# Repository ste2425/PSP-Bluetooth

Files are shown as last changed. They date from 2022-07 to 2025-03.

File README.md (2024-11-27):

# PSP-Bluetooth

--- 

ℹ️ **Name Change**  This project was formerly called the `PSP-Consolizer`. The project has since been renamed to `PSP-Bluetooth` as the term `Consolizer` usually makes people think of video output which this project never worked with. 

If you wish to see the legacy `PSP-Consolizer` project it is accessible on the `legacy` branch [here](https://github.com/ste2425/PSP-Bluetooth/tree/legacy)

---

This project aims to add Bluetooth controller support to the PSP 1k, 2k and 3k models using an ESP32.

---

It aims to solve to problems:

- [x] Using the PSP as a consolizer
- [ ] Using the PSP as a dockable console (like the Nintendo Switch)

## Progress so far
* Fully functional hardware that replaces the UMD drive
* Partially functional hardware for portable version
* Fully functional consolizer implementation that works for both the 2K and 3K consoles
* Fully functional firmware that offer configurable controller mappings and OTA updates
* Single click programming via a Web app for Serial and OTA programming. No extra tools needed, it downloads the binaries and does everything
* Partially functional controller mappings via the web app.

## Web app

The web app can be found here [PSP-Bluetooth](https://ste2425.github.io/PSP-Bluetooth/).

## Repository Structure

### /software

This contains the firmware for the ESP32. It is built using the Arduino core and maanaged via the Arduino CLI. To build it the cli needs to be installed with the command `arduino-cli` globally available. 

See [it's readme](./software/Readme.md) for more info.

### /installer

This contains the software for the Web app. It as an Angular application built using Angular Material and deployed to GitHub pages via GitHub Actions.

See [it's readme](./installer/README.md) for more info.

### /Hardware

This contians all the hardware files for custom FPC's and the mod board itself.

See [it's readme](./hardware/Readme.md) for more info.

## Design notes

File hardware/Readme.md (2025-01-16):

# Hardware

This is the source for the Kicad project for the PSP Bluetooth hardware.

# Parts

I use JLCPCB for my assembly and as such the parts used are sourced from their catalog.

## Adding a part

See [Changing Parts](./ChangingParts.md) for more info.

## Generating JLCPCB production files

See [Generating Gerbers](./GenerateGerbers.md) for more info.

# Projects

# Analog

FPC for the analog stick intercept for 2K PSP's. This allows us to inject analog stick values without soldering to the console.

# Buttons Super

FPC for all the buttons intercepts for 2k PSP's combined into a single project. Fabs usually charge extra for all being combined into one.

# Center Buttons

FPC for the center buttons intercept for 2K PSP'script

# ESP

Project for the Mod Board which supports both portable and consolizer

# ESP-C

Project for the Mod Board which only support consolizers. The analog multiplexer for the analog sticks are missing here.

# Right

FPC for just the right buttons for 2K PSP's

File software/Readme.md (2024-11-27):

# ESP32 Software

This is the firmware that runs on the ESP32.

# Setup

 To build it the Arduino CLI needs to be installed with the command `arduino-cli` globally available. 

 Once setup in the scripts folder run `install.sh`. This will install all the needed board definitions and cores. It will also install the various libraries needed. Some libraries are to packaged via Arduino and are stored as zip files within this repo.

 # Building

 If you just wish to compile/build the firmware run the script `compile.sh`. This will not merge the bootloader binaries to flash the ESP32.

 # Building && merging

 If you wish to compile/build the firmware and also merge the bootloader binary (The CI does this) run the `build.sh` script.

 We need to do the merging for when uploading to the ESP32 via the web app. *If uploading without the web app use the `upload.sh` script*

 # Building & Uploading

 If you wish to compile and upload the firmware locally run the `upload.sh` script.

------------------------

 ℹ **Default Port** ℹ

 ---------------------

 The scripts are hard coded with the default port the ESP32 appears on for my development machine. If this is different for you, you will need to change it.

 # GitHub Actions

 See the `buildPSPBluetooth.yml` file in the `.github/workflows` folder in the root.

 ## Release binaries for the web app Issue

 See the readme [here](../releaseBinaries/Readme.md)

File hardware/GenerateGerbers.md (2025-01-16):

# Generate Gerbers

When generate production files for use with JLCPCB i use a plugin. This generates the Gerbers, zips them and generates the BOM and placement files.

## 1: Install the plugin

Follow the instructions here [https://github.com/Bouni/kicad-jlcpcb-tools](https://github.com/Bouni/kicad-jlcpcb-tools) to install the plugin.

## 2: Generate files

Click `Tools -> External Plugins -> JLCPCB Tools` menu item.

In the menu that opens you can do various things, most commonly remove items from the BOM and placement files.

**NOTE** it often likes to place test pads in the BOM file even though there is no associated part.

If the items listed as `TestPoint` have a green tick under either `BOM` or `POS` you will first need to highlight them in the list. Then click either `Toggle BOM` or `Toggle POS` to remove them from those generated files.

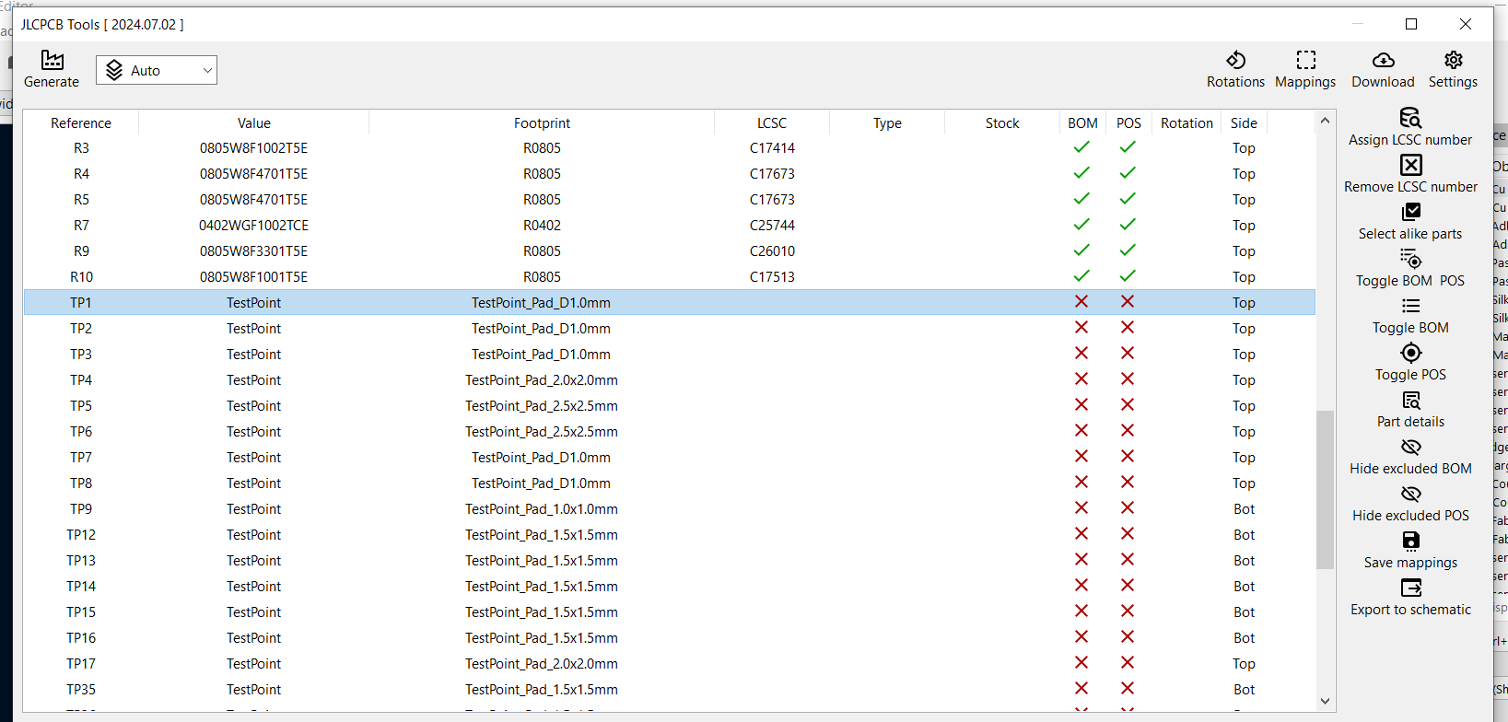
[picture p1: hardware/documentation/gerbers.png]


Once ready you can click `Generate` to generate the production files

## 3: Access files

The generated files will exist in `<clone-dir>PSP-Bluetooth\hardware\esp-c\jlcpcb\production_files` and can be uploaded to JLCPCB.

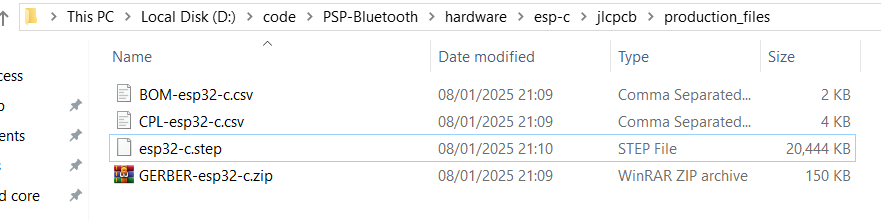
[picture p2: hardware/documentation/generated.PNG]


There may or may not be a `.step` file. This is just a 3D model of the PCB.

# Done

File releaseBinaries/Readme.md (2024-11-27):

# Release Binaries Folder

Due to CORS issues the web app can't download artifacts directly from a GitHub release. 

The CI instead commits back into the repository the compiled binaries in this folder. It then creates a new tag with the release number.

The web app then uses GitHub's RAW api and the release tag to find the binaries needed to flash to the ESP32.

**TLDR; ignore this folder and its contents, its for CI.**

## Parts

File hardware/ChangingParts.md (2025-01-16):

# Changing Parts

Sometimes it may be required to change parts, should some go out of stock.

This is my proccess.

## 1: Find the part

Using JLCPcb's part search is terrible IMHO. Instead i use a 3rd party here: [https://yaqwsx.github.io/jlcparts](https://yaqwsx.github.io/jlcparts).

The first time its used it will load up internally all the available parts to make them searchable. After that you have very fine grained search criteria to find exactly what you want.

### Considerations:
**Pick parts with footprints**. Whilst you can make your own, pick parts that have footprints.

Once you have found a part, click its part number.

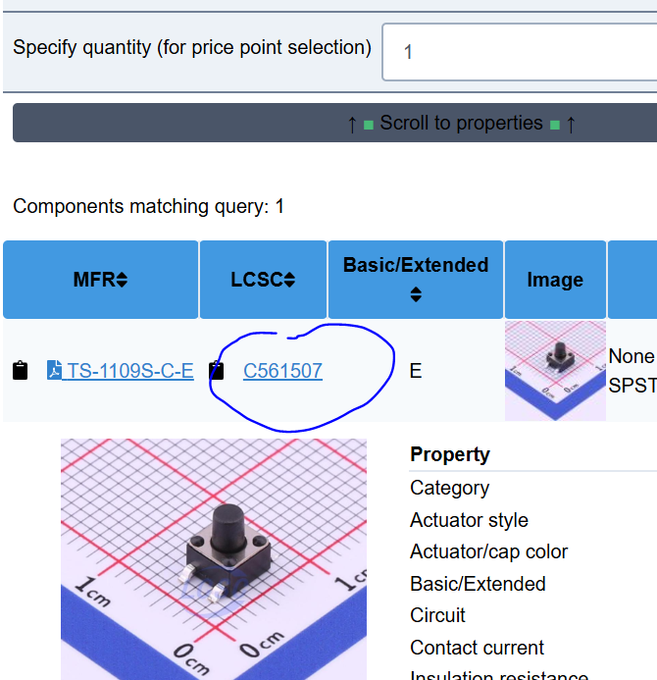
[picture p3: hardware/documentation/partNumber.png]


Then look the for `EasyEDA` button and click it.

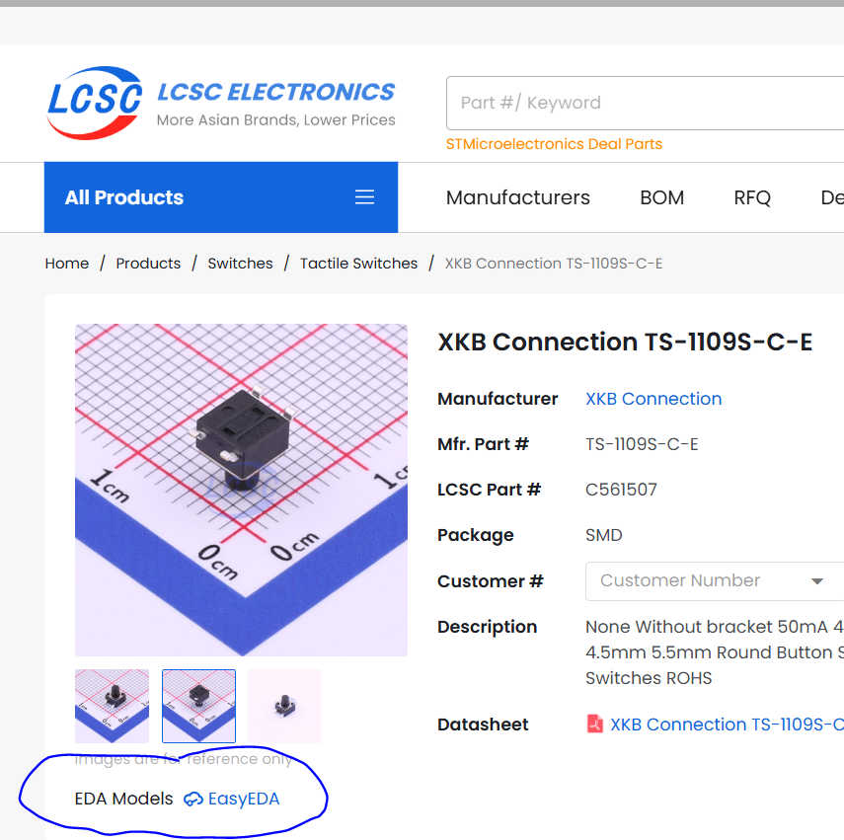
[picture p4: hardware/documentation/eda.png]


Then you can check its footprints.

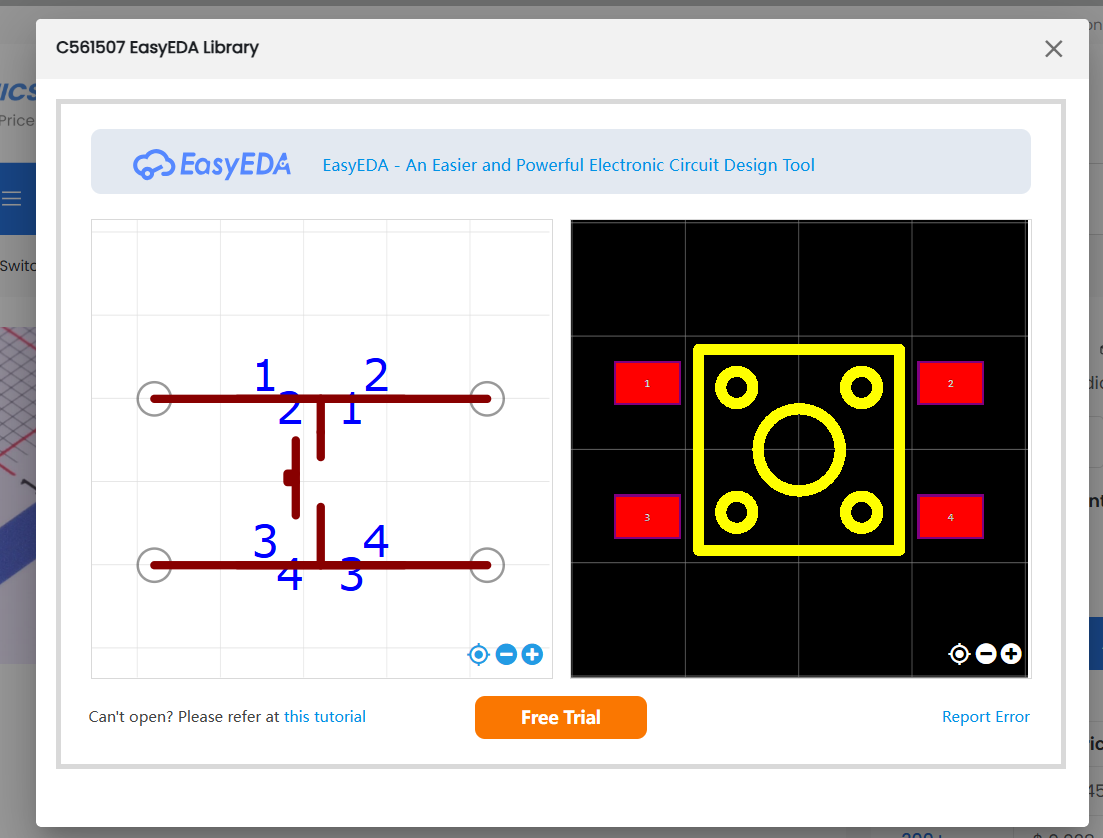
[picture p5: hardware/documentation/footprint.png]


Once you have found a part take note of its part number.

## 2: Add the part the the JLCPCB parts library

I run a script giving it the part number noted above. That script will download footprints for us and add them to a library linked to the projects in the repo. You can then use that part in any schematics.

**Don't have any projects open whilst running this script** Otherwise parts may not be available for use untill you close and re-open the Kicad project.

This script used a 3rd party python tool which can be installed from here: [https://github.com/TousstNicolas/JLC2KiCad_lib](https://github.com/TousstNicolas/JLC2KiCad_lib).

To sun simply right click the script `AddJLCPCBPart.ps1` and select `Run With Powershell`

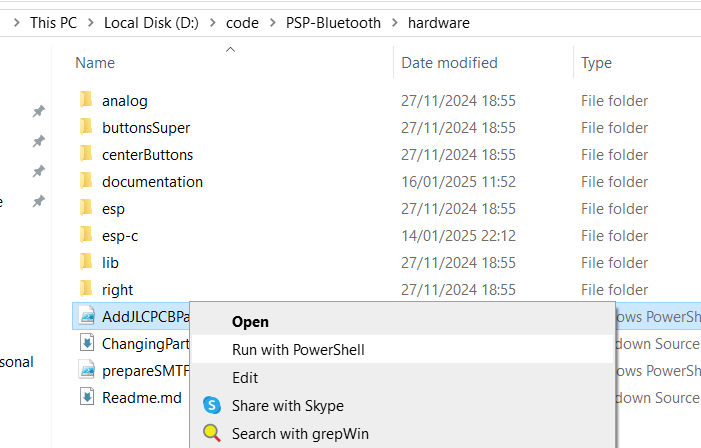
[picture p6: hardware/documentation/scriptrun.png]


In the terminal that opens paste the part number and press enter.

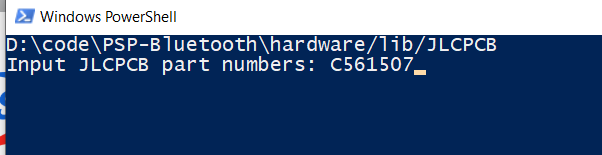
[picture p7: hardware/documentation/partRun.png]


Once done it will ask for another part number. You can either add more or close the terminal.

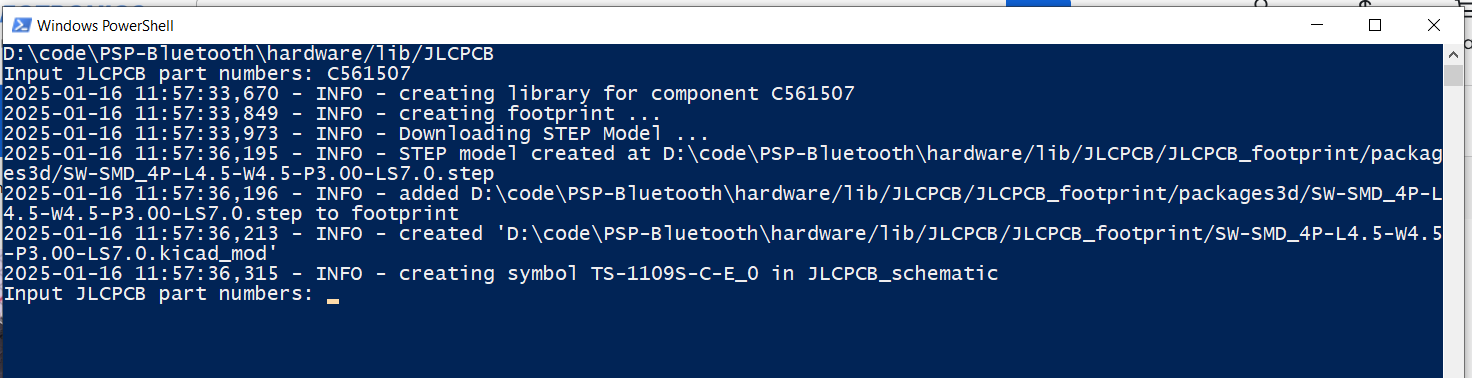
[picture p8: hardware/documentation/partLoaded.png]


The part is now available for use in KiCad

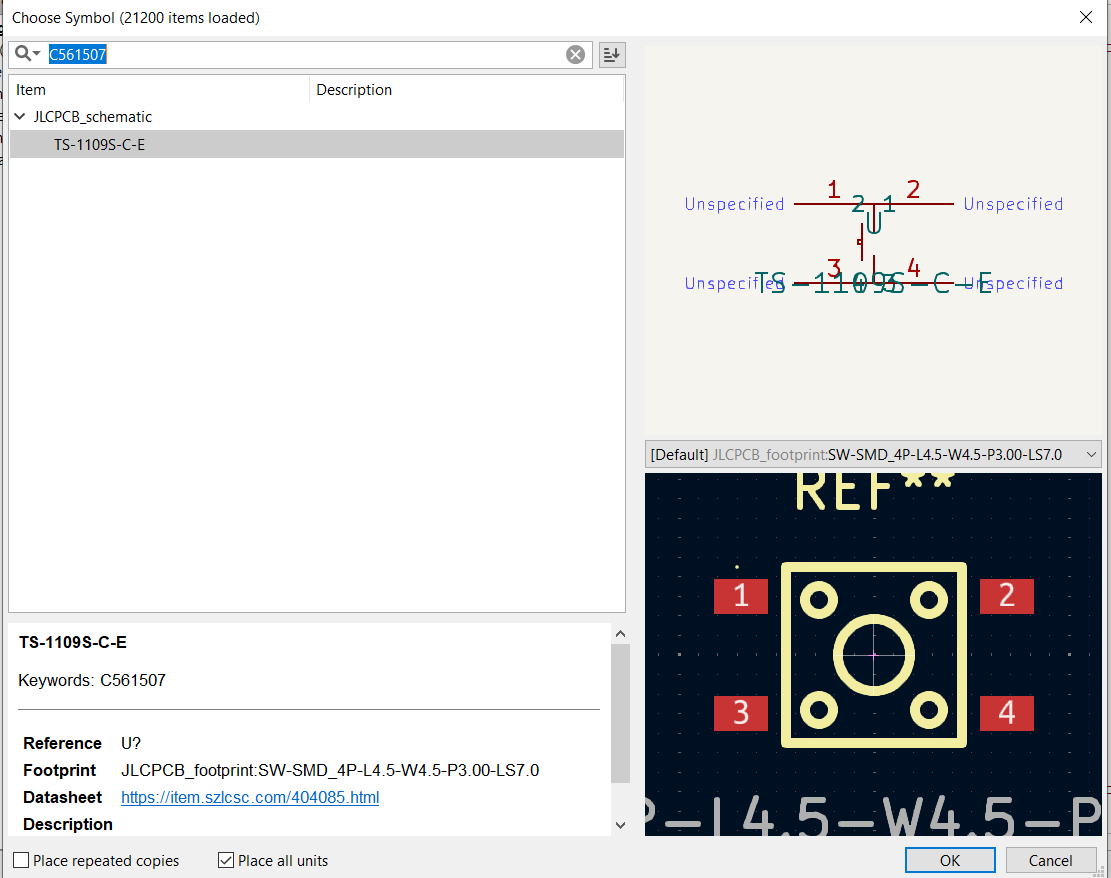
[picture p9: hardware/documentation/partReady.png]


## 3: Update Schematic

I would then remove the old part from the schematic and add in the new part, routing it correctly.

## 4: Update PCB

Then in the PCB Editor i would update the PCB from the schematic.

This will full in the footprints for the new components.

It will **not** remove the footprints for the old components.

I'd first delete the old footprints, then clean up the unused traces and via's using the `Tools -> Cleanup Track and Via's` menu item.

I would then place and route the new components footprints.

# Done

And that should be it, hopefully.

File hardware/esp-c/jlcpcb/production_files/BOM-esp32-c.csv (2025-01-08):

Comment | Designator | Footprint | LCSC
MCP23008-E/ML | U1,U4 | QFN-20_L4.0-W4.0-P0.50-BL-EP2.7 | C144211
CL21A106KAYNNNE | C13,C6,C9 | C0805 | C15850
0805W8F1002T5E | R2,R3 | R0805 | C17414
0805W8F1001T5E | R1,R10 | R0805 | C17513
0805W8F4701T5E | R4,R5 | R0805 | C17673
1N5819WS | D1,D10,D11,D12,D13,D2,D20,D21,D22,D23,D24,D25,D26,D27,D28,D29,D3,D4,D5,D6,D7,D8,D9 | SOD-323_L1.8-W1.3-LS2.5-RD | C191023
SS8050_C2150 | U3,U8 | SOT-23-3_L2.9-W1.3-P1.90-LS2.4-BR | C2150
TC1109DE26048 | U14,U15 | SW-TH_3P-L4.5-W4.5-P1.8-LS3.0 | C22459542
0402WGF1002TCE | R7 | R0402 | C25744
0805W8F3301T5E | R9 | R0805 | C26010
CL21B105KBFNNNE | C5 | C0805 | C28323
TS-1187A-B-A-B | BOOT1 | SW-SMD_4P-L5.1-W5.1-P3.70-LS6.5-TL-2 | C318884
MICROXNJ | USB1 | MICRO-USB-SMD_MICROXNJ | C404969
CL21A226MAQNNNE | C1,C11 | C0805 | C45783
AFC42-S14FMA-1H | U13 | CONN-SMD_14P-P0.50_L3.1-W9.0 | C466533
CC0805KRX7R9BB104 | C10,C12,C2,C4,C8 | C0805 | C49678
IPFP051A30472R5 | U7 | FPC-SMD_4P-P0.50_C9900013912 | C5127055
HC-FPC-05-09-10RLTAG | U10,U11,U6 | FPC-SMD_10P-P0.50_HC-FPC-05-09-10RLTAG | C5213750
MCP42010T-I/SL | U5 | SOIC-14_L10.0-W5.5-P1.27-LS7.8-BL | C54781
AMS1117-3_3 | U9 | SOT-223-3_L6.5-W3.4-P2.30-LS7.0-BR | C6186
ESP32-WROOM-32E(4MB) | U12 | WIFI-SMD_ESP32-WROOM-32E | C701341
CH340C_C7464026 | U2 | SOP-16_L10.0-W3.9-P1.27-LS6.0-BL | C7464026
FC-2012HRK-620D | LED1 | LED0805-R-RD | C84256

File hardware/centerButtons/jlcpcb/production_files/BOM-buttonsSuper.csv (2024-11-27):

Comment | Designator | Footprint | LCSC
5034801000 | P1 | FPC-SMD_5034801000 | C127355

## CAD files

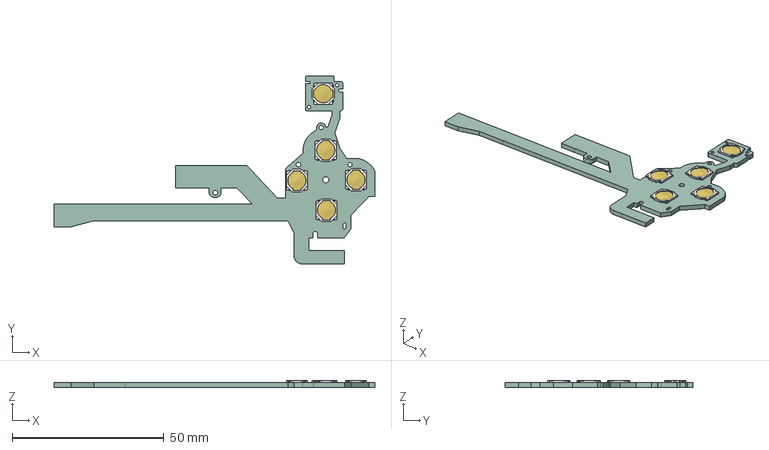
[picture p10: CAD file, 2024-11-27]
hardware/right/right-fpc.step
105.9 x 62.0 x 2.35 mm
KEY-SMD_4P-L7.5-W7.0-H0.6-P5.0 x 5
right_PCB

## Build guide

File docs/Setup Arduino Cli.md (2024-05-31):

# Setup Arduino Cli

* sudo apt-get update
sudo apt-get install python3-pip
pip3 install pyserial

arduino-cli compile --fqbn esp32-bluepad32:esp32:esp32 .
Traceback (most recent call last):
  File "/home/stephen/.arduino15/packages/esp32/tools/esptool_py/4.5.1/esptool.py", line 31, in <module>
    import esptool
  File "/home/stephen/.arduino15/packages/esp32/tools/esptool_py/4.5.1/esptool/__init__.py", line 41, in <module>
    from esptool.cmds import (
  File "/home/stephen/.arduino15/packages/esp32/tools/esptool_py/4.5.1/esptool/cmds.py", line 14, in <module>
    from .bin_image import ELFFile, ImageSegment, LoadFirmwareImage
  File "/home/stephen/.arduino15/packages/esp32/tools/esptool_py/4.5.1/esptool/bin_image.py", line 14, in <module>
    from .loader import ESPLoader
  File "/home/stephen/.arduino15/packages/esp32/tools/esptool_py/4.5.1/esptool/loader.py", line 30, in <module>
    import serial
ModuleNotFoundError: No module named 'serial'

Used platform         Version Path
esp32-bluepad32:esp32 4.0.4   /home/stephen/.arduino15/packages/esp32-bluepad32/hardware/esp32/4.0.4
Error during build: exit status 1

arduino-cli compile --fqbn esp32-bluepad32:esp32:esp32 .

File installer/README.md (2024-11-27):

# Installer

This is the source code the the Angular Web app.

It is built in TypeScript and uses Angular Material for its UI components.

It also uses Web Serial and Web Bluetooth API's for programming the ESP.

Serial programming is provided by the [ESPtool-js](https://github.com/espressif/esptool-js) library provided by ESpressif.

As such it only works on Chromium bases browsers.

# Release binaries for the web app Issue

See the readme [here](../releaseBinaries/Readme.md)

# Installation

Ensure NodeJS is installed and the command `npm` is globally available.

Within the `installer` folder run `npm install`.

# Starting

Within the `installer` folder run `npm start`. The terminal output will report the URL for the web app locally.

# Hosting in GitHub

See the `buildPSPBluetoothWebProgrammer.yml` file in the `.github/workflows` folder in the root.

## Routing problem

The app is hosted within GitHub and deployed using GitHub actions. There was some jiggery-pokery to make the routing work.

GitHub expects a static site where every page is its own `html` file. Angular is an SPA where there is a single root `index.html` file and routing is handled via JS.

These two worlds clash. If you hit the root of the site, navigate to another page say `/serial` then hit F5 you will get a `404` page from GitHub. This is because GitHub is looking for a html file called `serial.html` which obviously does not exist.

### Routing Solution

The solution is to duplicate, via CI, the compiled `index.html` and rename it for every route the application has.

## Route Case Sensitivity Problem

GitHub pages routes are case sensitive. IF the route is `/serial` but you hit `/Serial` it will get a `404`.

What we do is have a `404.html` page in the root which GitHub actions hits. Some JS checks the current URL, lower cases it and compares it to a list of expected routes. If it matches it will redirect the user to that correct casing of that route.

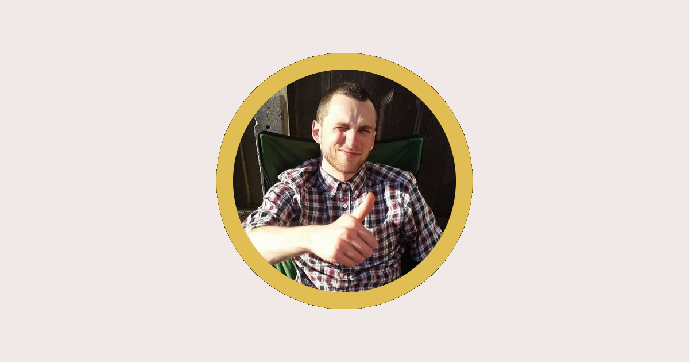
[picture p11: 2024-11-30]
installer/src/assets/thumb.png

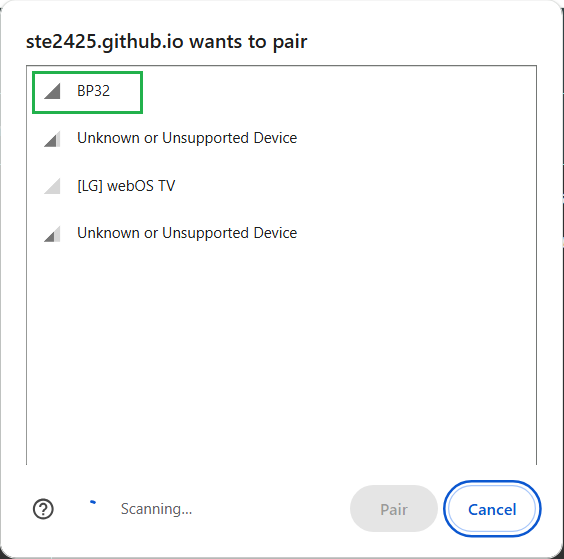
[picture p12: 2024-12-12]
installer/src/assets/pairDialog.png

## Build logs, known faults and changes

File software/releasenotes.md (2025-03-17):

# Release 2.3.2 - PRE RELEASE

## Features
 N/A
## Changes

## Saving mappings doesnt reset active mapping
When saving mappings via the web editor the currently active mapping will remain the active mapping.

However this is based on mapping number. Imagine you have three configured mappings, with the last one active.
If a mapping is deleted so there is now only 2 active mappings. In this situation the currently active mapping will still be reset back to mapping one.

## Bug fixes

## Saved button mappings not applying correctly

When saving button mappings via the Web UI they were not saving correctly when a controller is connected.

Now they should update correctly. Note: *The active mappings resets to the first mapping*.

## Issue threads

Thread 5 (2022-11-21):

Build buttons mappings tool via USB

ste2425, 2022-11-21:
Build a utility that will allow the user to create custom button mappings.

Once inplace this will allow for future enhancements such as per game mappings.

The ideal solution will be a Web APP communicating with the Arduino via Web Bluetooth however until https://github.com/ricardoquesada/bluepad32/issues/30 is implemented thats not possible.

Instead build an electron app that comms with the Arduino via serial.

It should be built in scuch a way that the Core is re-useable within a web app and the serial comms are abstracted such that they could be relaced with BT comms when aforementioned feature request is complete.

In theory much of the ground work will be done here so that when its possible to use Bluetooth comms instead of Serial it wont be a big task.

Closed 2023-06-02.

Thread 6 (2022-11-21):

Implement quick shutdown

ste2425, 2022-11-21:
Currently the Consolizer will shutdown when a controller turns it self off, disconnecting.

The time this takes varies per controller the PS4 takes around 7-8 seconds holding the PS button. XBOX one S controller take around 3 seconds holding the XBOX button.

Instead we should instruct the controller to turn it self off. That way the shutdown time can configurable by the user, defaulting to a much shorter time. It can also be consistent across all controllers.

Initial WIP implemented on branch `feature/quickShutdown` but relies on the following https://github.com/ricardoquesada/bluepad32/issues/26 to go live in version `3.5.2`

Closed 2024-07-22.

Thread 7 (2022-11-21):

Build internal hardware version

ste2425, 2022-11-21:
There is enough space in the PSP to fit an Arduino inside if the UMD drive was removed.

Building a PCB to fit all needed hardware _should_ work and be reasonably easy.

The difficulty is finding a way to connect the original PSP's face buttons and the Arduino to the PSP's connectors at the same time.

I have tried numerous ideas and the best option seems to be to replace the original button FPC's with custom ones that provide easy access solder pads to connect the Arduino too.

However looking to have these made in a low volume prototype stage seems terrible expensive and beyond my means as a hobby project.

If anyone with greater hardware skills than mine (i don't have much) could figure this out that would be great, i would happily make any needed software changes.

Here are a couple of blog posts on the subject if people would like to see more information on my investigations.

https://ste2425.github.io/21/12/2022/PSP-Internal-Consolizer-Making-Connections/
https://ste2425.github.io/08/01/2023/PSP-Internal-Consolizer-Fitting-FPCs/

**As of right now (3/4/223) this feature is on hold**. Currently this is a consolizer project and will remain that way. In the future when either my skills improve, or my disposable income increases i will re-investigate this feature.

ste2425, 2024-07-22:
So this is in active developent and going well targeting an ESP.

A PCB is current 1/3 of the way through being designed. Once done targeting other PSP's, such as the 3000 or 1000 should be allot easier as all that is needed is custom FPC's specifically for those consoles.

However arguably the 1000 is only useful with the HDMI mod installed too, however that also occupy the UMD space so can't be used at the same time.

ste2425, 2024-11-07:
In yet so version is pretty much done and being built as the standard for the ESP32 platform.
closing this as internal is just the norm now and not an additional feature like it was the for Arduibo.

Closed 2024-11-07.

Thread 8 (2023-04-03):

Implement PSP 3000 support

Bma36, 2023-04-03:
I want to make it for my psp 3000, is it compatible? do you have twitter to follow your work?

ste2425, 2023-04-03:
It currently doesn't support the 3000 yet.

The pinout of the various internal connectors on the 3000 is different to the 2000. Sadly i don't have a 3000 to figure out the pinout of these connectors and modify the hardware to make it compatible.

It would be an easy task to make it compatible but i won't be in a position to purchase a 3000 for a while to investigate.

If you, or anyone else interested in this project, has a 3000 and the ability to open it and figure out that pinout i would happily make the changes needed to support it.

Bma36, 2023-04-03:
Yes, I have a psp 3000 and I can help you by dismantling and taking photos of the connectors, your twitter is restricted, you can't follow it, if you want the connectors' records just say so.

https://twitter.com/Am60691019?t=VmD2-d7xX93HxiJeVbyZvA&s=09

this is my twitter if you can follow it so i can follow back i'll be grateful

Bma36, 2023-04-05:
https://github.com/DobaMuffin/PS2PSP

this is another project to use the ps2 controllers made based on the psp 2000 and was adapted for the 3000, maybe it can help you

Bma36, 2023-04-08:
Up

hpx1984, 2024-05-09:
hi Sir ste2425

how about PSP1000, is it can support too?

Doyle4, 2024-07-19:
From looking at Issues I can see this project is no longer worked on or the dev is not interested in peoples requests, did anyone find a alternative that works on all?

ste2425, 2024-07-19:
Pleas try to avoid passive aggression in order to get a developers attention and/or try an pressure them into working on something for you.

I am actively working in this and I’d you check my YT you would see somewhat regular uodates on this project.

I am doing this in my own time for fun. As such I will be working on it in a timescale that’s fits around my personal and family life.

If you or anyone else for that matter wishes to contribute to help move this project forward I’d happily collaborate with others.

Right now the ESP is working. You can controll all the PSP’s buttons and I’m 1/3rd the way through designing the PCB to fit in the UMD space.

I will try and more regularly push to this repo and post YT videos on the project though.

Doyle4, 2024-07-22:
Passive aggressive?
May 9th 2024 most recent issue, then its a whole year a question was asked unanswered, May 2023, not passive aggressive, clear statement to what looked liked an abandoned project.

Did you run out of bubblewrap to protect yourself from words? Damn…

ste2425, 2024-07-22:
@Doyle4 there is no need to end your comment with sarcasm or just generally being unpleasant.

Let’s try and keep this civil shall we, this isn’t Twitter. If you are wanting me to continue building something for you to use at no cost to your self that is probably the best way to go about it.

Like I say if you wish to contribute to this project to move it along faster I will gladly accept PR’s.

I you wish to help push forward 3000 support open your PSP3000 and send me high res scans of the button FPC’s both sides and back. This is what I lack as I do not own a 3000 yet.

ste2425, 2024-11-07:
Just an update.

3k should be supported now. For consolizers the latest hardware variant should support it out the box.

Portables will need custom FPC’s which when I’m finished to firmware I will build. They are just variants on the 2k however so should be very quick to do.

ste2425, 2025-02-19:
Closing this. All variants of the psp 2 and 3k are fully supported .

Closed 2025-02-19.

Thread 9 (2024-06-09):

Updates for you I filmed a video tutorial!!

Shtonksareup, 2024-06-09:
Hey there @ste2425,

So I may have gone overboard... haha I just got my set up semi video ready and I really wanted to film a tutorial because 1. I saw people commenting on your short saying it was fake since their is no tutorial, which is dumb but what ever. 2. I was looking for this exact project for what felt like ages, and every reddit post claims its impossible.... well clearly not. I want to make sure you get all the credit for your work though. I just put the thing together and filmed it. I will add a google drive link to the video so you can watch it. Ignore the audio for now, I plan to put graphics on it and dub over my voice for directions. Since I do a full psp teardown and the install. I want people to be able to skip around the tutorial as easy as possible. The only thing I will say in the video that is feedback on the current BOM is that the Right 14pin connector cable I think should be opposite sided, not the A type. both builds I did I had to get funky with the cable to get it to fit in right, but the opposite side one would let you do two angled bends and fit the right way :). I will explain that in the video the rest will literally just be a video form of your build guide with a little extra direction and help for people who are visual.

I have a small YT channel with my brother where we play games, but I would not be upset if you felt like the video should be posted on your channel since you did all the work :D you take a look at the video and let me know what you think.

PS ( I had to watch a YT video on how to submit an issue, for the first time ever I know how my parents feel when I help them with their email or other various tech issues haha)

Here is the link for the video with no audio dubbing yet
[Video Link](https://drive.google.com/file/d/1I4zoUzjQbjUgBxGIB0SeaWKbQubcTaRH/view?usp=sharing)

I am also working on a potential shell the can be printed and will cover the system, that will take more time since I have to wait for my prints to finish and then test and correct. But I have a cool design i am starting to like :D

Edit: Here is the default base
[PSP defult BT PCB mount.zip](https://github.com/user-attachments/files/15807657/PSP.defult.BT.PCB.mount.zip)

I also finished and tested my custom shell. Here are the files for that as well
[PSP Custom Shell Base and Top.zip](https://github.com/user-attachments/files/15807700/PSP.Custom.Shell.Base.and.Top.zip)

Shtonksareup, 2024-06-10:
@ste2425 Not a problem at all! I am coming off a super busy period myself and starting Wednesday I have am taking a bunch of time off since I am a teacher. I figure you will respond when you can so no rush on that kind of stuff.

I have always loved taking things apart so I wanted to make videos about that, but just don't really have the time haha! This just felt like the perfect thing to film especially with there not being one out there yet.

Don't change what your doing at all! I think splitting them into two projects makes the most sense, but I honestly wouldn't do anything else with the BT project in terms of soft ware. It is fun you say your a software guy and hardware isnt your thing I tell my friends the exact opposite. It was so nice for me that all I had to do is plug the Arduino in and hit run. That is honestly what most people would want. Thats why I don't think you need to change anything or offer additional features to the "external BT build" All I wanted as PS controller button support so I could play a few of the PSP games I love on the big screen. With out getting to technical and off track. I think a lot of people aright now are getting home set ups with upscalers, that's the reason I even wanted to do the build in the first place.

Back on track, I think if you split it into two things and we add the video link/ stl files for the new external shell ( its super basic but adds a little protection. Then leave that project alone. I have played for around 10 hours or so on and off over the past few weeks and I have only ever had it desync once on me and all i did was press the button on the PCB and i was playing again. So I am sure there are people who would want more from you and there are more features that people would want but put all that work into the new project. The old one can be for people like me who have a psp with a busted screen, of in my case I had a MOB that no matter how many different 2000 umd drives I tried it still wouldn't read disks. So something on the board was messed up and I held onto if for parts, but it was the perfect board for this build. Plus if the video helps some people build it and it catches any steam I am sure someone else would pop in and mess around with the Arduino if they really wanted to.

I watched your video about the current updates, and I think there is a whole group of people that would like the new build you are working on and the fact that it would work for all models would be great. (There are lots of comments asking for that im guessing cause people want to use what ever psp they already have) This project though wasnt to expensive. I bought enough parts for 2 builds and with the tv cable and the second PSP i bought it cost me like $200 USD I have a break down in the graphics I am adding to the video. I think for a bit over $100 a lot of people will want to do this build. The modding community is huge, and some mods are way to expensive. I did one on my original Nintendo a few weeks ago and the parts alone cost me $120. Im getting off topic again though sorry.

Summing up. You should work on what makes you excited. Its a fun project so don't change what your cause I have time put into the old project. I think they both have uses, and I think people will enjoy building them both or just one or the other for their needs. If they want plug and play and have a broken PSP like me then they are in luck. If they want way more freedom, and control buttoned down into the old shell then you have that in the works and they could help/ keep tabs on the project! you keep doing what you are doing. I think the split into a finished or released version of the external build and then a in the works internal build would be perfect.

I will stop going on and on now haha. I am away for the next day and a half, but I am hoping to finish the video by Friday, I had to do some final reprints last night and I want to film the extra shell assembly.

Shtonksareup, 2024-06-10:
@ste2425 I got the chance to get the shell printed, so use this video link, I will check my email to make sure I approve your request this time. [Video with the shell at the end](https://drive.google.com/file/d/1I4zoUzjQbjUgBxGIB0SeaWKbQubcTaRH/view?usp=sharing)

Shtonksareup, 2024-06-13:
Alright @ste2425 Here is the link to the finished video, I sent an email over to you, but Im not sure if they made it so I am adding it here for you to take a look at. Make sure I got your name right! :D
[Video with all finished audio](https://drive.google.com/file/d/1l1CTqXvrykbftFFA1gyGjSH0_6XYXhdx/view?usp=sharing)

ste2425, 2024-06-13:
hey @Shtonksareup sorry I've been meaning to respond the past couple of days.

The video is fantastic. Super good quality and in-depth.

I think i will publish a new release with your version of the mount stl as it looks allot better than what ive built.

Really interesting point about the firmware upgrade and TVout, i never considered that and certainly something to be aware of.

Are you on twitter/discord/YT? Would you be open for a DM to chat about this project? I'll be easier to get hold on on one of those platforms.

Shtonksareup, 2024-06-13:
@ste2425 Thank you so much for saying all of that I really appreciate it!! Yeah I am on discord and youtube I probably check discord more though if you give me your discord name I will add you mine is zeldandlink that should work. :D DM would be way easier.

ste2425, 2024-06-14:
@Shtonksareup Neat, ive ive done it right i should have sent a request over to you. Or if not some random internet person!

Shtonksareup, 2024-06-14:
@ste2425 I think I added you. I sent a little message :) if you didnt get one then I added some one else 👀

Closed 2024-07-16.

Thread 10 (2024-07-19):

really 140 Ohm Resistor?

Liriel-666, 2024-07-19:
really 140 Ohm Resistor for the LED? Thats a Really unusale Resistor and hard to find.
Most sell only 130 or 150 Ohm als normal.
140 ohm as smd yeah easy to find

ste2425, 2024-07-22:
Hey, to be honest when i designed the PCB i didn't know any better! I think i arrived at value either from a guide i followed or some resistor calculator.

If there is a better value you can recommend i will gladly update it to help others.

ste2425, 2024-11-07:
Closing this. The schematic being reference is for e older Arduino version. The newer ESP version doesn’t have such issues, I don’t think.

Feel free to re-open and Ofer a PR to fix if this issue still exists.

Closed 2024-11-07.

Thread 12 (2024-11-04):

Pressing X Puts the PSP to Sleep?

Grae87, 2024-11-04:
Hi, sorry if this is something basic, but everything seems to work except the X button. When I press it, the console goes to sleep.

I've checked continuity with all the points. I can't find any bridging or cold solder points.
No issues came up with the Arduino flash either.

Can anyone help?

ste2425, 2024-11-04:
The FFC which controls the PSP’s power button is on the same connector as the X button (and all the others on that side for that matter)

My first port of call would be to verify the FFC is correctly seated at both ends. Also ensure is is not obviously damaged.

When building this many times I had nudged one of the cables causing behaviour like this.

Once one of them had an internal break causing similar behaviour but that seems rarer from my experience

ste2425, 2024-11-26:
Closing this as stale. Please re-open if any new information is available.

Closed 2024-11-26.

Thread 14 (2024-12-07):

Future feature of V2 BT Mod Board (visually logging the paired controller button presses)

Shtonksareup, 2024-12-07:
Of all my ideas I think this has the most quality of life potential for future users. A display on the mappings page that shows the user the current mapping for a button they are pressing on their controller. This would allow users to identify the current settings in real time allowing for greater ease of use over the large variety of compatible controllers.

Most AAA/ huge tech companies follow the same basic layout for controllers but for something like an xbox adaptive controller, or a retro BLE controller where the layout is significantly different this would allow users to see what the buttons are mapped as and change them as they see fit.

Great work as always Stephen and no rush or timeline on this idea just logging so I don't forget about it.

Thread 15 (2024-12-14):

How to program from localhost?

Darthagnon, 2024-12-14:
The current implementation looks like it depends on https://ste2425.github.io/ to program the controller - is it possible to program instead from a website running off my laptop, or via USB? I would prefer not to depend on a website that will be 404 in a few years to program hardware.

ste2425, 2024-12-14:
Thanks for the interest in my project!

First of all https://ste2425.github.io/ is me, it is my GitHub username and all the various URLS off that are my repositories with GitHub pages configured, ‘PSP-Bluetooth’ being this repository.

This repository contains *everything* needed for the PSP-Bluetooth project to function, the hardware files, firmware source and the web app source. The readme documents this and explains the repository structure.

So long as this repository exists the web app will exist, so essentially so long as the project exists the web app will!

hopefully that alleviates any concerns you have @Darthagnon.

However everyone are free, and encouraged, to fork this repository. Make changes and enhancements.

So if you wish you can fork the repo and follow the instructions in the read me to run the web app locally.

ste2425, 2024-12-16:
As there’s been no response going to consider this problem solved. Please reopen if still having concerns.

Darthagnon, 2024-12-24:
Thank you for the info! I will try running the website from the repo off localhost.

I was a bit worried as similar projects that used direct-from-web updates for writing firmware (e.g. [Google Stadia](https://garyodernichts.blogspot.com/2023/01/looking-into-stadia-controller.html), [Henlo for PS Vita](https://github.com/SKGleba/henlo_jb)) did not work offline and needed extra work to be suitable for long-term usage.

ste2425, 2024-12-24:
It’s also worth adding for programming the web app is purely a convenience.

You can download the binaries from the release and program the ESP32 using your referred programming method.

Closed 2024-12-16.

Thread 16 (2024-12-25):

Setting cycle through mappings to stick click and Select + Start + left or right on dpad

Shtonksareup, 2024-12-25:
Just logging this so we don't forget. that button combo will be weird to do with one hand but I think every controller will have those buttons where some will not have thumb stick buttons.

ste2425, 2025-02-07:
Closing as fixed in version 2.2.0.

There will be enhancements to this in #19

Closed 2025-02-07.

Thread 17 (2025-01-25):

コントローラーの右スティックの斜め入力

niasuniasu, 2025-01-25:
コントローラーの右スティックをD-Padに設定した時、斜め入力が出来ないのですが、出来るようになりますか？

ste2425, 2025-02-02:
This is something i was hoping i would get away with not being an issue.

Lets say the range of the analog stick is -250 - 250. To trigger a button press it has to be over 20 from the end of its range (so -230 or 230).

Trouble is because the analog stick gate is a circle if the stick is in the top left diagonal the left value may be something like -200 and the top value 200. So they are outside the threshold to trigger a value.

I could lower the threshold but that would make the analog stick feel too sensitive for some.

I need to have a think, i have an idea on how to detect if its a diagonal.

Jonnicom, 2025-02-03:
I am glad to see both this and the other issue that you combined with an earlier submitted one are at least on the radar.  I agree, the right stick works ok as it is, but it would be nice to see some type of diagonal integration eventually.  Thanks for all you do, this is a great project!

ste2425, 2025-02-04:
The pre-release build 2.2.0-rc2 has a fix for this implemented.

I have lowered the thresholds slightly and diagonals work in my testing.

It feels ok to me but that is very subjective.

Feel free to give it a try (can be installed from the web app using BLE).

I will consider this resolved if i don't hear otherwise :)

thanks.

Jonnicom, 2025-02-05:
> It feels ok to me but that is very subjective.

Subjective indeed!  It's going to be different for everyone, and perhaps even game-to-game, just depending on how the player is trying to implement it.

I have my right stick on a Dualsense mapped to the PSP Dpad, and after testing it in Metal Gear Solid: Portable Ops, it works, but it is very picky.  Have to be pointing precisely at the 45 degree angles, or you'll still just get up or right/up or left, etc.

But, in practice it is working and seems possible.  I guess adjustments can be tested from here on out.  I wonder if there is any way to implent the user being able to adjust this sensitivity on their own in the future.  But, I am also aware that we're essentially mapping 4 buttons in an attempt to "fake" 4 additional directions.

I'll keep testing it any other games I can think of in the next few days and give more feedback to try to help out!

ste2425, 2025-02-05:
Thanks for testing this out so quick!

Yea I was on the fence if this would be acceptable or not. Decided to wait for use feedback.

It would be good to have it user controllable.

Need to try and set sensitivity for the four directions and the four diagonals seperatIy i think.

Lowering the threshold any more to account for diagonals I think will reign the feel of  the four main directions if that makes sense.

I think rather than over engineering at this stage I will make it configurable. If it turns out that isn’t enough to make both the  diagonals and the four main directions comfortable then we will have to rethink.

Sent from Outlook for iOS<https://aka.ms/o0ukef>
________________________________
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

ste2425, 2025-02-07:
Closing as fixed in version 2.2.0.

There will be enhancements to this in https://github.com/ste2425/PSP-Bluetooth/issues/19

Specifically to make the diagonals work better.

Closed 2025-02-07.

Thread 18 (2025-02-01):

L1 + R1 + Right D-Pad doesn't allow Right D-Pad to work

Jonnicom, 2025-02-01:
I am using a DualSense PS5 controller on a PSPlaceable and have not had the change to test any other controller at this time.  But, when using L1 as L on the PSP, R1 as R on the PSP, and Dpad as Dpad, pressing right on the DPad will not work if you also have L1 and R1 held down.  Can be repeated and demonstrated in games such as Metal Gear Solid Portable Ops 1 and 2.  What's odd is, mapping the L and R functions on the PSP to L2 and R2 on the controller works fine...

ste2425, 2025-02-02:
This is linked to #16 i think.

The button combo `L1` & `R1` & `DPAD Right` is a reserved combo that cycles through to the next configured button mapping.

The reason `L2` / `R2` works is because that is not checked for this reserved mapping.

I thought it would be unuque enough, i didn' realise there were games which used it.

Closing this as i think #16 will solve this problem. Please comment on that issue if that combo wont work.

Closed 2025-02-02.

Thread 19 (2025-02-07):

Add extra config options

ste2425, 2025-02-07:
Add a UI to configure the following things

* Power LED brightness
* Threshold to trigger button press when controllers with analog triggers are  mapped to buttons.
* Threshold to trigger button press when analog stick is mapped to buttons.
  * This includes dealing with diagonals better.
* Ability to make button combo les difficult
  * Option to juse use `select` & `start` or use `select` & `start` & `R1` & `L1`

Jonnicom, 2025-02-08:
Very much looking forward to the work on the right stick and thresholds, etc!  The current build did enable it, but I don't think it's sensitive enough.  It is extremely specific in Metal Gear Solid Portable Pps, and doesn't work at all how you'd want it to when mapped to the face buttons for a first person shooter like Ghost in the Shell.  But, that's just what I've found in my testing so far.  Glad it's on the radar!

ste2425, 2025-02-14:
@Jonnicom FYI there is a prelease version 2.3.0-rc4.

Along with a new settings page in the web app.

If you have the time maybe you could give it a try. It allows a number of different settings to be toggled, analog stick threshold being one of them.

It is very experimental so you may encounter issues though!

Jonnicom, 2025-02-15:
@ste2425 Tested/Testing now, but yes, wow, what a difference lowering the threshold makes!  Feels closer to real analog input than ever before.

It's still obvious that it's a "gated" 8 direction input, but, I think that's the best you can get considering it was never true analog directional control to begin with.  Still much prefered to use this than using the 4 face buttons to move a camera, especially in first person shooters.  In fact, when in quick movement and motion, you almost can't *tell* that it's gated 8 directions, it does feel rather fluid with the threshold all the way down.  Great job!  I also tested the trigger sensitivity using a dualsense, I can't really feel much of a difference either way myself, but I'm not sure if the dualsense even uses analog triggers or if I'd notice either way!

Out of curiosity, is the analog threshold setting for adjusting just the right stick, or both left and right at the same time?

I don't see any change in the LED brightness, however - not a huge issue, may vary from controller to controller as well.

Sidenote, made a video reviewing the PS Placeable project, singing high praises - thought you may wanna see it, and I didn't know where else to send it to you!  https://youtu.be/HCmnLQwp4ZM?si=6qqm9faSwKQYEQ1I

ste2425, 2025-02-15:
@Jonnicom  Just watched your video and it was very impressive. Its great to see this project out there in the wild being used and enjoyed by people :)

I do have a couple of questions.

* i noticed that on the controller mapping screen the images of the PSP and the Controller look odd, washed out. Do you have an special settings in your browser/operating system for high contrast mode or something similar? This is how id expect it to look.

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

However in your video it looked like this:

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

Would be good to get that fixed!

* Other question you mention it got into a confused state where it thought the PSP on when it was off etc. If you have a chance could you log an issue and add any info how you got into that state? I would like to investigate just to be sure.

Back to this issue specifically thats great news its working for you, could you share the value you set the analog stick threshold to and ill set that as the default.

I have pushed a new RC version which allows changing the button to shut down the console. (at this stage its a fixed alternative combo. If there's enough demand i can ehance further but that would be somewhat more involved).

Anyway thanks for the feedback and testing, has made fixing these issues much easier!

Jonnicom, 2025-02-18:
Hey!  Sorry it took me a while to get to a PC so I could type up a decent response - bad at typing on a phone.

First, yes, the images you have on your end are correct, and the reason they look that way in my browswer is because I use a high-contrast dark mode plug-in, so that's completely on my end!

As for the on/off switch up issue, I think I ended up figuring out the real issue is with the PPrefs plugin that I use, it uses the home button, which brings up the menu, and freezes the console when it's trying to turn off - that's why I thought the option to use other buttons or button combos to turn the console on and off may be a good option, since so many CFW plugins use weird buttons or hold buttons to turn on and off, etc.  Such as PPrefs using the home button, CFW using the select button, and CWcheat using the select button held down for a few seconds to activate.

ste2425, 2025-02-18:
@Jonnicom not a problem thanks for getting back to me.

So im just testing a few more changes. One is an additional shutdown combo instead of the home button like you mention.

The other is a low battery indicator for controllers.

Once done i think this release will be ready.

ste2425, 2025-02-18:
Marking this as complete. Version 2.3.0 should now resolve all the issues mentioned.

Closed 2025-02-18.

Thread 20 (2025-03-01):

PSP Bluetooth release-2.3.0  have issues with TV out not enabling

Cyrus331, 2025-03-01:
I flashed the Release 2.3.0 firmware, but there is a startup sound but no screen. What is the reason?

Cyrus331, 2025-03-01:
The problem was solved. The CENTER and LEFT cables were reversed.

But another problem is that when playing God of War, the character runs around and the analog joystick is out of control. What should I do? The wires have been checked and everything is connected.

ste2425, 2025-03-01:
Can you share a picture of the soldering?

That behaviour is usually a sign of something nkt connected or wires soldered to  the wrong points.

When you move the stick does it have any impact? If it does on which axis? Up or down?.

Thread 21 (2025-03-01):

Trouble flashing firmware

schweaty, 2025-03-01:
I'm having a lot of issues flashing the firmware to the board.  I can't get the computer to recognize it.   I've tried at least 15 usb cables at this point.  All I have access to are Mac's.  Either there is a compatibility problem with Mac's or the board is DOA.  This is extremely frustrating.

ste2425, 2025-03-01:
Which browsers are you trying to use?

Unfortunately I don’t own a MAC however I would expect any chromium based browser to detect the board regardless of the underlying OS.

One way to rule out the web app/browser being the issue would be to try and program it via the Arduibo IDE. Which I understand is a pain having to setup the ESP32 core but that way you can be certain that if that doesn’t work you have a hardware issue.

If it is a hardware issue it’s possible it could just be the USB to Serial adapter.

On my version of the boards I expose the RX and TX pins of the ESP32 to allow for external serial adapters. I don’t know if Dan has kept those pads accessible (assuming it’s one of Dans boards you have) but that is another option.

schweaty, 2025-03-01:
I'm using chrome, but I dont think it's a browser issue.  The computer (a MacBook Pro and old iMac) just are not seeing the board when I plug it in via usb.

ste2425, 2025-03-01:
Ok. Are you sure all your USB cables a data and not just power? I know you said you tried multiple but just to be sure so you have any other device you can test the cables with?

If you have either a USB -> Seriwl adapter or an old Arduino Uno you can bypass the onboard USB to Serial chip just incase that is at fault.

schweaty, 2025-03-01:
I just checked mist of the cables using an Xbox controller.  At least half of them do carry data.  None of them connected the blutooth board to the computer.  I do not have a USB to serial or arduino uno.

schweaty, 2025-03-01:
It just occurred to me I could use my android phone with a USB hub in desktop mode.  Plugged in the USB and it did not detect it.  I got another error message in chrome about serial web not ebabled so I don't think I could have lashed it even if it was detected.

ste2425, 2025-03-02:
Interesting, if you haven’t enabled it yet coukd you share pictures of what the page looks like?

It should do feature detection and detect if you have Web Serial enabled. It should disable the buttons in the UI if not to prevent you even trying.

schweaty, 2025-03-02:
The Serial option under program was disabled in chrome.  My initial conclusion is that the only way to flash th8s board is on a windows PC

ste2425, 2025-03-02:
Ok. Closing this as it’s a known limitation of web serial that it is a very experimental technology with only Chromium based support.

However Chrome not working on MacOS is a little surprising (or maybe. It considering Safari’s stance is against the technology).

As I don’t have a Mac I can’t investigate much. I’ll look into trying to detect if the User is using a Mac and show a message explaining the situation.

Besides that though I think there is not allot I can do.

I may add a Manual programming option. If someone has no choice but to use Mac you can download the binary and flash it via the Arduino IDE. That would be an option for Mac only users as a work around.

Closed 2025-03-02.

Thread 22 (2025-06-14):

Unable to flash

salt86, 2025-06-14:
I can't seem to flash the board through USB. I'm getting this error

```
Downloading binary...
Downloaded, size: 879136
Getting connection to ESP...
esptool.js
Serial port WebSerial VendorID 0x1a86 ProductID 0x7523
Connecting...
AggregateError: All promises were rejected
```

Also using the serial monitor outputs this

`NetworkError: Failed to execute 'open' on 'SerialPort': Failed to open serial port.`

I am using Chrome on Linux. I did attempt using Chromium, but couldn't find any serial ports as easily.

ste2425, 2025-06-16:
@salt86 sorry been trying to respond to this all weekend and it refused to load comments.

Anyway glad you found a work around. I think ill add in the wizard a note saying you can manually download the binaries and flash using any ESP32 flasher tool people prefer. Just in case the webapp refuses to work (the tech is experimental sadly).

Anyway what distro were you running? I tested it on Ubuntu right at the start of the project and it worked for me then, however its possible something changed since then.

If you have the time could you open the console in your browsers dev tools and try again? Its possible it may log more info there that my error handling isn't catching. (Note dev tools needs to be open before trying to flash it otherwise logs may be missed).

I'll try and repro it my end and see if there is anything that can be done.

salt86, 2025-06-17:
Unfortunately, I had some trouble getting the ribbon cables clamped in to the module due to my breaking the ribbon cable clamps. That being said, I'm afraid to take the PSP out of its shell. I will post my specs though:

```
$ uname -a
Linux Blue 6.11.0-26-generic #26~24.04.1-Ubuntu SMP PREEMPT_DYNAMIC Thu Apr 17 19:20:47 UTC 2 x86_64 x86_64 x86_64 GNU/Linux
```
i also know that it was detected via `lsusb`

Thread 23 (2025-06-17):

Options and Share button are swapped in Configuration page diagram

salt86, 2025-06-17:
The Options and Share button are swapped in the controller diagram. The text reads correctly (aside from the fact that PS4 buttons are labeled Share and Options instead of Capture and Options.)
The controller maps according to the text.

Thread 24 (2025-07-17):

about PSP2K   analog X, analog Y, and PX, PY

Cyrus331, 2025-07-17:
Why is there two sides of the PSP 2K ribbon cable, analog X, analog Y, and PX, PY? Can I combine analog X with PX, analog Y with PY on the ribbon cable? If I solder directly, do I solder to PX PY? I saw that the PCB version of retromodworks.com has been updated, and there is no AX, AY.

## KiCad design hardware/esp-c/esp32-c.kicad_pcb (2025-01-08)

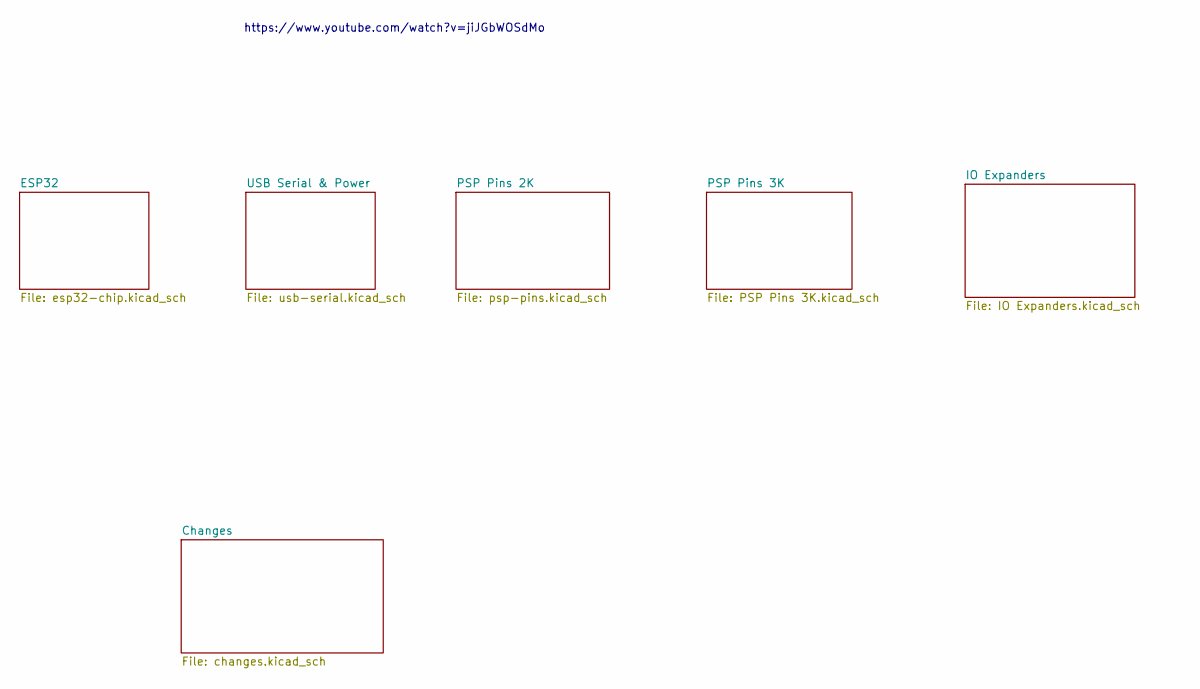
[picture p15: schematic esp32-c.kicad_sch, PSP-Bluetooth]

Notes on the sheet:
https://www.youtube.com/watch?v=jiJGbWOSdMo

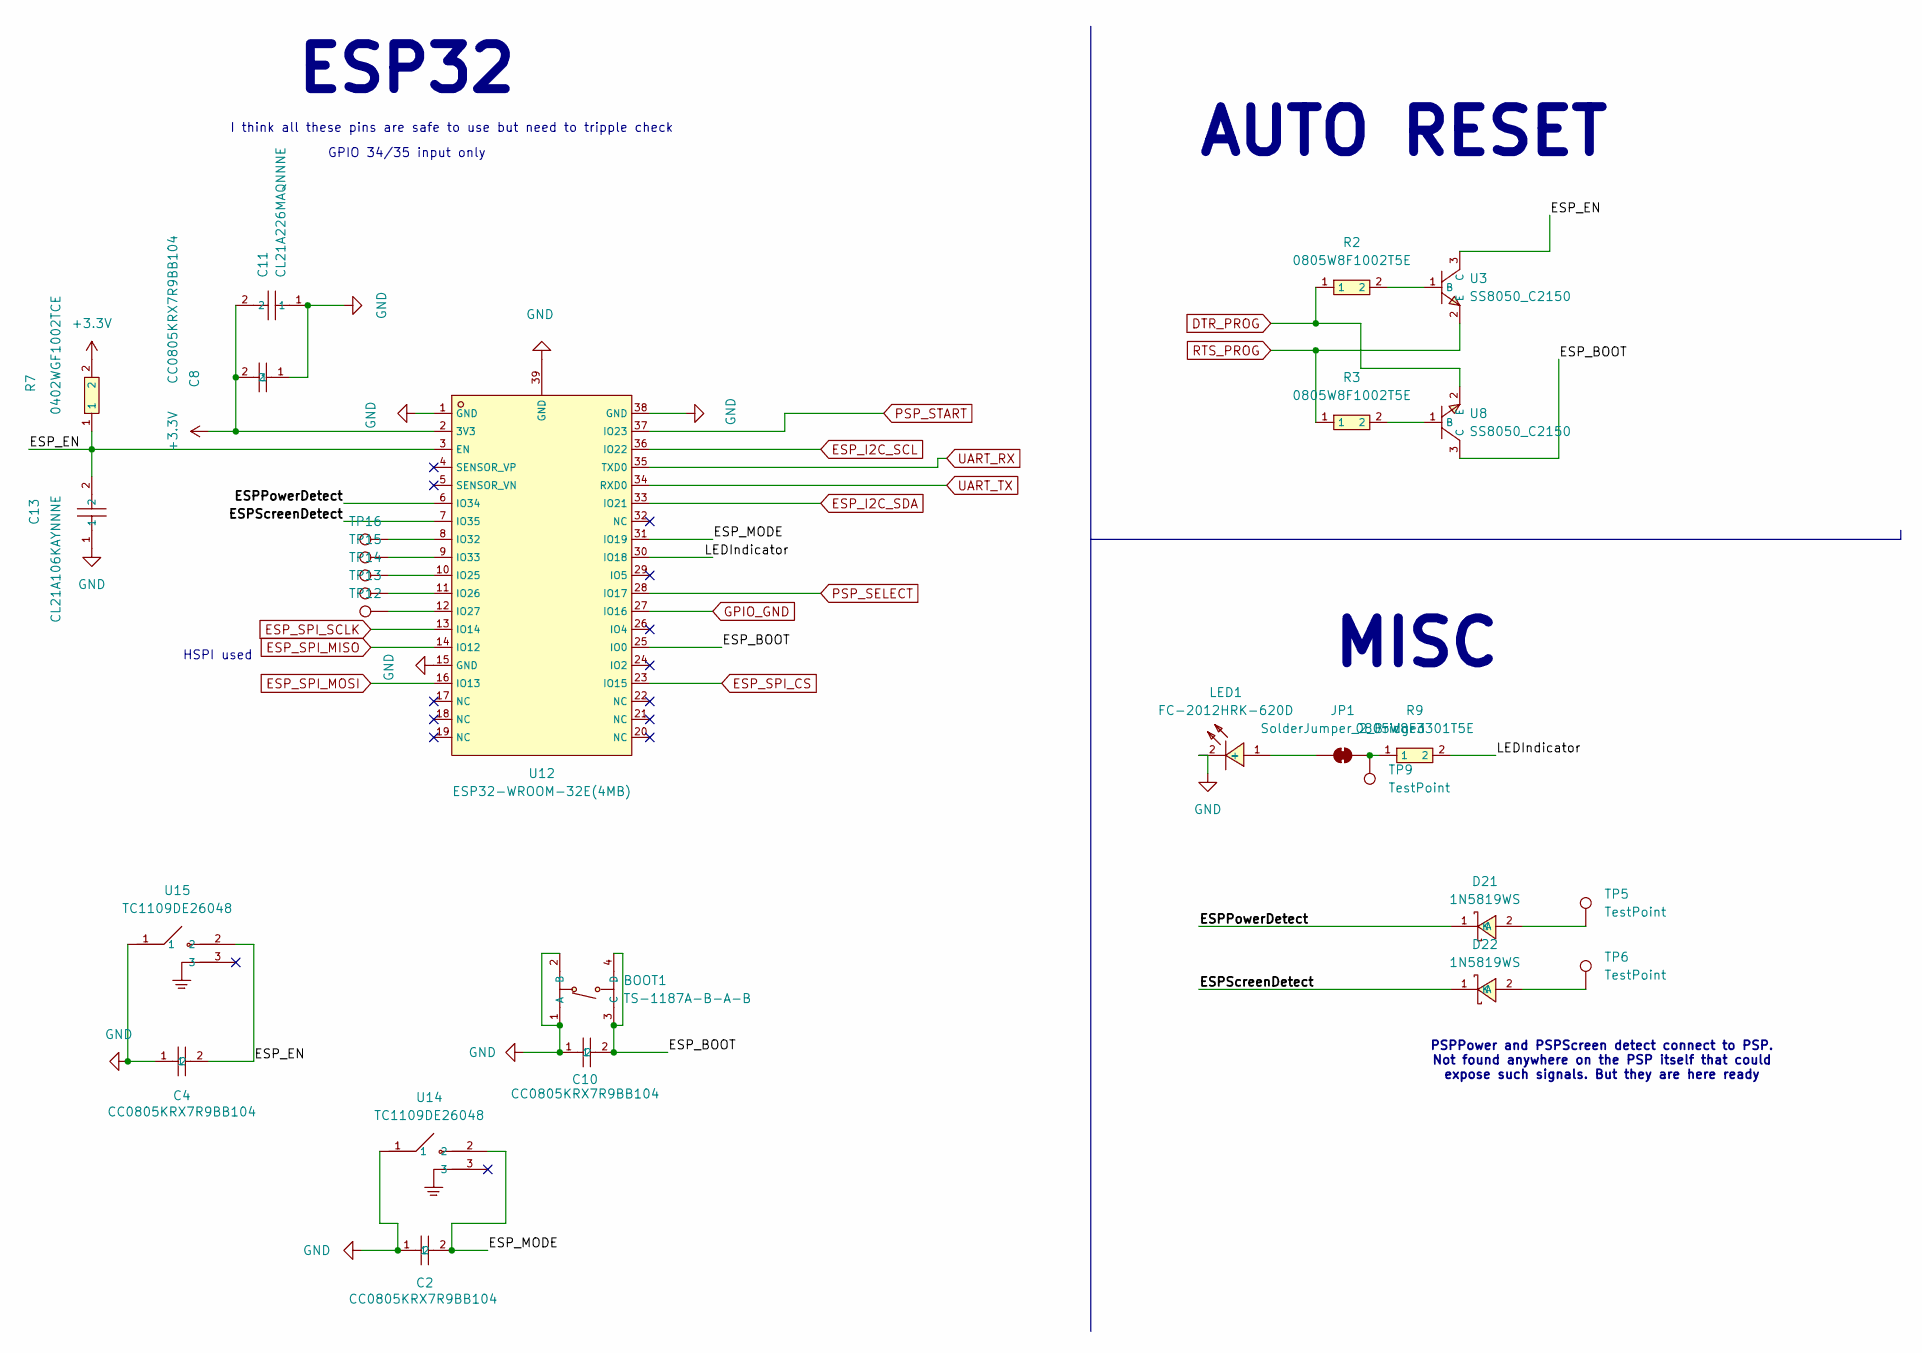
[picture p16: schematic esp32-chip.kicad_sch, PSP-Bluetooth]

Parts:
BOOT1: TS-1187A-B-A-B; SW-SMD_4P-L5.1-W5.1-P3.70-LS6.5-TL-2; LCSC C318884
C2, C4, C8, C10: CC0805KRX7R9BB104; C0805; LCSC C49678
C11: CL21A226MAQNNNE; C0805; LCSC C45783
C13: CL21A106KAYNNNE; C0805; LCSC C15850
D21, D22: 1N5819WS; SOD-323_L1.8-W1.3-LS2.5-RD; LCSC C191023
JP1: SolderJumper_2_Bridged; SolderJumper-2_P1.3mm_Bridged_Pad1.0x1.5mm
LED1: FC-2012HRK-620D; LED0805-R-RD; LCSC C84256
R2, R3: 0805W8F1002T5E; R0805; LCSC C17414
R7: 0402WGF1002TCE; R0402; LCSC C25744
R9: 0805W8F3301T5E; R0805; LCSC C26010
TP5, TP6: TestPoint; TestPoint_Pad_2.5x2.5mm
TP9: TestPoint; TestPoint_Pad_1.0x1.0mm
TP12, TP13, TP14, TP15, TP16: TestPoint; TestPoint_Pad_1.5x1.5mm
U3, U8: SS8050_C2150; SOT-23-3_L2.9-W1.3-P1.90-LS2.4-BR; LCSC C2150
U12: ESP32-WROOM-32E(4MB); WIFI-SMD_ESP32-WROOM-32E; LCSC C701341
U14, U15: TC1109DE26048; SW-TH_3P-L4.5-W4.5-P1.8-LS3.0; LCSC C22459542

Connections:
+3.3V: C8.2, C11.2, R7.2, U12.2 (3V3); also elsewhere on the board
/ESP32/ESPPowerDetect: D21.1 (K), U12.6 (IO34)
/ESP32/ESPScreenDetect: D22.1 (K), U12.7 (IO35)
/ESP32/ESP_BOOT: BOOT1.3 (C), BOOT1.4 (D), C10.2, U8.3 (C), U12.25 (IO0)
/ESP32/ESP_EN: C4.2, C13.2, R7.1, U3.3 (C), U12.3 (EN), U15.2
/ESP32/ESP_MODE: C2.2, U12.31 (IO19), U14.2
/ESP32/LEDIndicator: R9.2, U12.30 (IO18)
DTR_PROG: R2.1, U8.2 (E); also elsewhere on the board
ESP_I2C_SCL: U12.36 (IO22); also elsewhere on the board
ESP_I2C_SDA: U12.33 (IO21); also elsewhere on the board
ESP_SPI_CS: U12.23 (IO15); also elsewhere on the board
ESP_SPI_MISO: U12.14 (IO12); also elsewhere on the board
ESP_SPI_MOSI: U12.16 (IO13); also elsewhere on the board
ESP_SPI_SCLK: U12.13 (IO14); also elsewhere on the board
GND: BOOT1.1 (A), BOOT1.2 (B), C2.1, C4.1, C8.1, C10.1, C11.1, C13.1, LED1.2 (-), U12.1 (GND), U12.15 (GND), U12.38 (GND), U12.39 (GND), U14.1, U15.1; also elsewhere on the board
GPIO_GND: U12.27 (IO16); also elsewhere on the board
unnamed: D21.2 (A), TP5.1
unnamed: D22.2 (A), TP6.1
unnamed: JP1.1 (A), LED1.1 (+)
unnamed: JP1.2 (B), R9.1, TP9.1
unnamed: R2.2, U3.1 (B)
unnamed: R3.2, U8.1 (B)
unnamed: TP14.1, U12.10 (IO25)
unnamed: TP13.1, U12.11 (IO26)
unnamed: TP12.1, U12.12 (IO27)
unnamed: TP16.1, U12.8 (IO32)
unnamed: TP15.1, U12.9 (IO33)
PSP_SELECT: U12.28 (IO17); also elsewhere on the board
PSP_START: U12.37 (IO23); also elsewhere on the board
RTS_PROG: R3.1, U3.2 (E); also elsewhere on the board
UART_RX: U12.35 (TXD0); also elsewhere on the board
UART_TX: U12.34 (RXD0); also elsewhere on the board

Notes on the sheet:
ESP32
HSPI used
PSPPower and PSPScreen detect connect to PSP. Not found anywhere on the PSP itself that could expose such signals. But they are here ready
AUTO RESET
I think all these pins are safe to use but need to tripple check
GPIO 34/35 input only
MISC

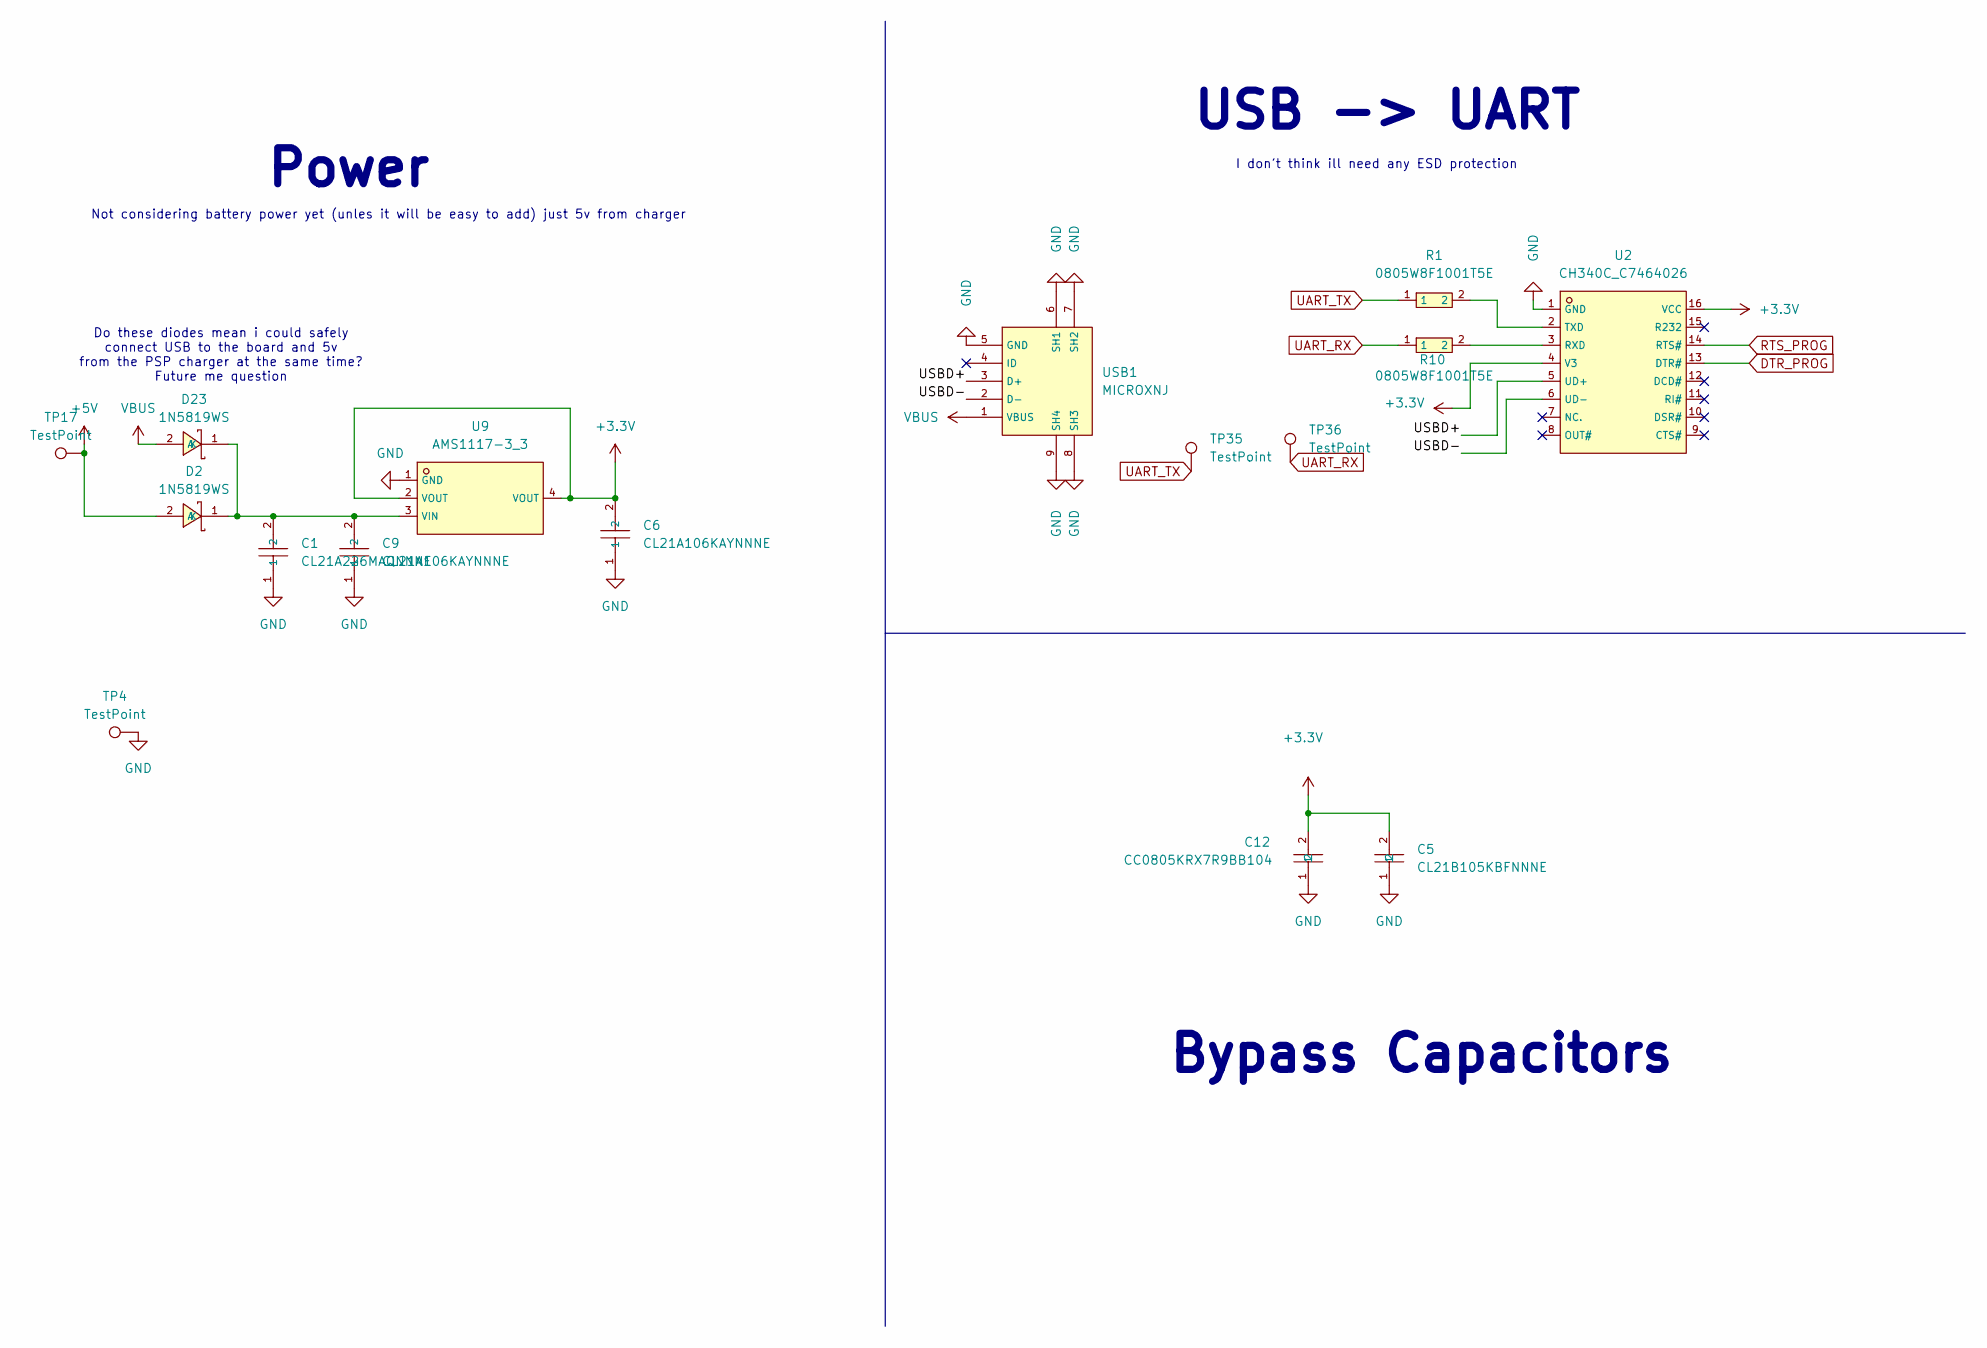
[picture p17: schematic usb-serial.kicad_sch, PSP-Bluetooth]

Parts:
C1: CL21A226MAQNNNE; C0805; LCSC C45783
C5: CL21B105KBFNNNE; C0805; LCSC C28323
C6, C9: CL21A106KAYNNNE; C0805; LCSC C15850
C12: CC0805KRX7R9BB104; C0805; LCSC C49678
D2, D23: 1N5819WS; SOD-323_L1.8-W1.3-LS2.5-RD; LCSC C191023
R1, R10: 0805W8F1001T5E; R0805; LCSC C17513
TP4, TP17: TestPoint; TestPoint_Pad_2.0x2.0mm
TP35, TP36: TestPoint; TestPoint_Pad_1.5x1.5mm
U2: CH340C_C7464026; SOP-16_L10.0-W3.9-P1.27-LS6.0-BL; LCSC C7464026
U9: AMS1117-3_3; SOT-223-3_L6.5-W3.4-P2.30-LS7.0-BR; LCSC C6186
USB1: MICROXNJ; MICRO-USB-SMD_MICROXNJ; LCSC C404969

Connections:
+3.3V: C5.2, C6.2, C12.2, U2.4 (V3), U2.16 (VCC), U9.2 (VOUT), U9.4 (VOUT); also elsewhere on the board
+5V: D2.2 (A), TP17.1
/USB Serial & Power/USBD+: U2.5 (UD+), USB1.3 (D+)
/USB Serial & Power/USBD-: U2.6 (UD-), USB1.2 (D-)
DTR_PROG: U2.13 (DTR#); also elsewhere on the board
GND: C1.1, C5.1, C6.1, C9.1, C12.1, TP4.1, U2.1 (GND), U9.1 (GND), USB1.5 (GND), USB1.6 (SH1), USB1.7 (SH2), USB1.8 (SH3), USB1.9 (SH4); also elsewhere on the board
unnamed: C1.2, C9.2, D2.1 (K), D23.1 (K), U9.3 (VIN)
unnamed: R10.2, U2.3 (RXD)
unnamed: R1.2, U2.2 (TXD)
RTS_PROG: U2.14 (RTS#); also elsewhere on the board
UART_RX: R10.1, TP36.1; also elsewhere on the board
UART_TX: R1.1, TP35.1; also elsewhere on the board
VBUS: D23.2 (A), USB1.1 (VBUS)

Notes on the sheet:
Bypass Capacitors
Power
Not considering battery power yet (unles it will be easy to add) just 5v from charger
Do these diodes mean i could safely connect USB to the board and 5v from the PSP charger at the same time? Future me question
I don't think ill need any ESD protection
USB -> UART

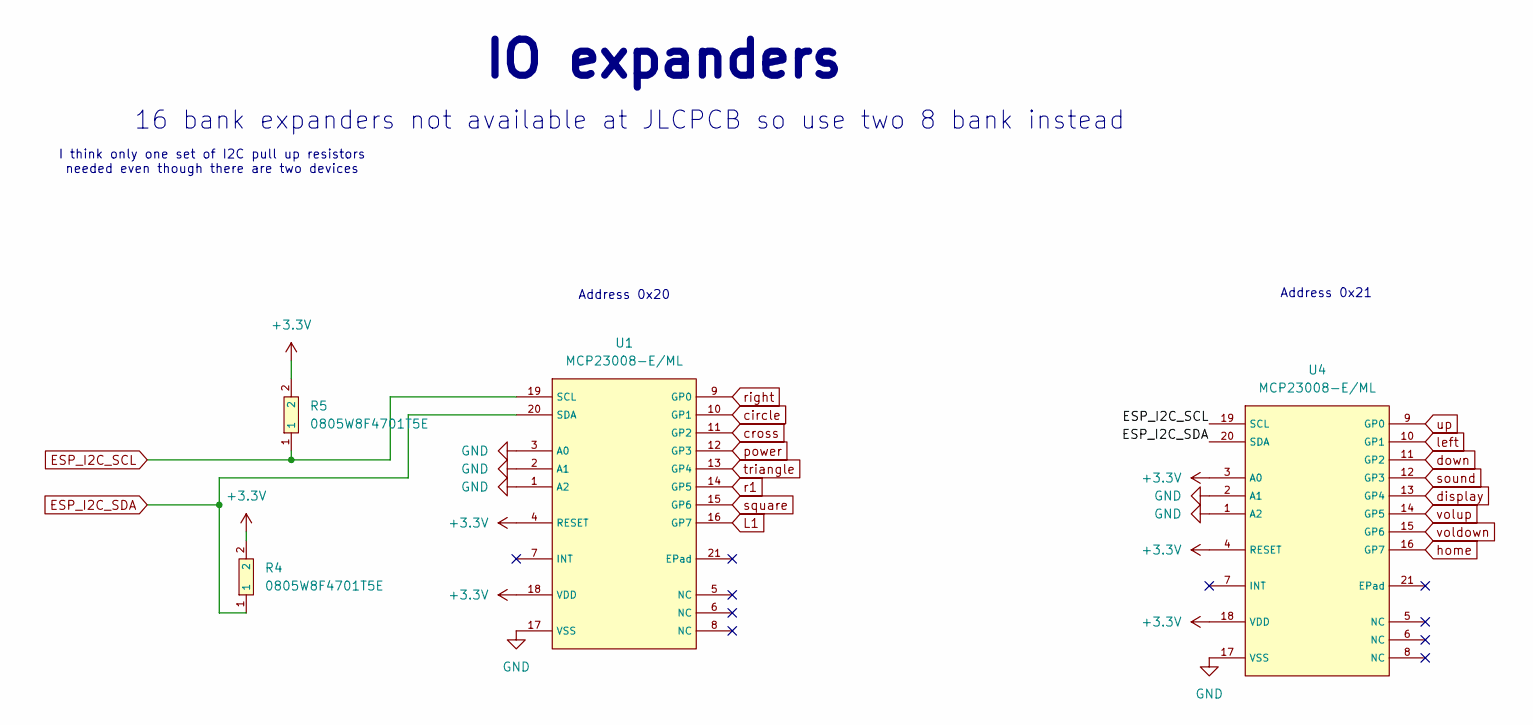
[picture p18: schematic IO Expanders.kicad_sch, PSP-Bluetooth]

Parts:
R4, R5: 0805W8F4701T5E; R0805; LCSC C17673
U1, U4: MCP23008-E/ML; QFN-20_L4.0-W4.0-P0.50-BL-EP2.7; LCSC C144211

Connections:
+3.3V: R4.2, R5.2, U1.4 (RESET), U1.18 (VDD), U4.3 (A0), U4.4 (RESET), U4.18 (VDD); also elsewhere on the board
ESP_I2C_SCL: R5.1, U1.19 (SCL), U4.19 (SCL); also elsewhere on the board
ESP_I2C_SDA: R4.1, U1.20 (SDA), U4.20 (SDA); also elsewhere on the board
GND: U1.1 (A2), U1.2 (A1), U1.3 (A0), U1.17 (VSS), U4.1 (A2), U4.2 (A1), U4.17 (VSS); also elsewhere on the board
L1: U1.16 (GP7); also elsewhere on the board
circle: U1.10 (GP1); also elsewhere on the board
cross: U1.11 (GP2); also elsewhere on the board
display: U4.13 (GP4); also elsewhere on the board
down: U4.11 (GP2); also elsewhere on the board
home: U4.16 (GP7); also elsewhere on the board
left: U4.10 (GP1); also elsewhere on the board
power: U1.12 (GP3); also elsewhere on the board
r1: U1.14 (GP5); also elsewhere on the board
right: U1.9 (GP0); also elsewhere on the board
sound: U4.12 (GP3); also elsewhere on the board
square: U1.15 (GP6); also elsewhere on the board
triangle: U1.13 (GP4); also elsewhere on the board
up: U4.9 (GP0); also elsewhere on the board
voldown: U4.15 (GP6); also elsewhere on the board
volup: U4.14 (GP5); also elsewhere on the board

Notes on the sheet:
Address 0x20
16 bank expanders not available at JLCPCB so use two 8 bank instead
Address 0x21
I think only one set of I2C pull up resistors needed even though there are two devices
IO expanders

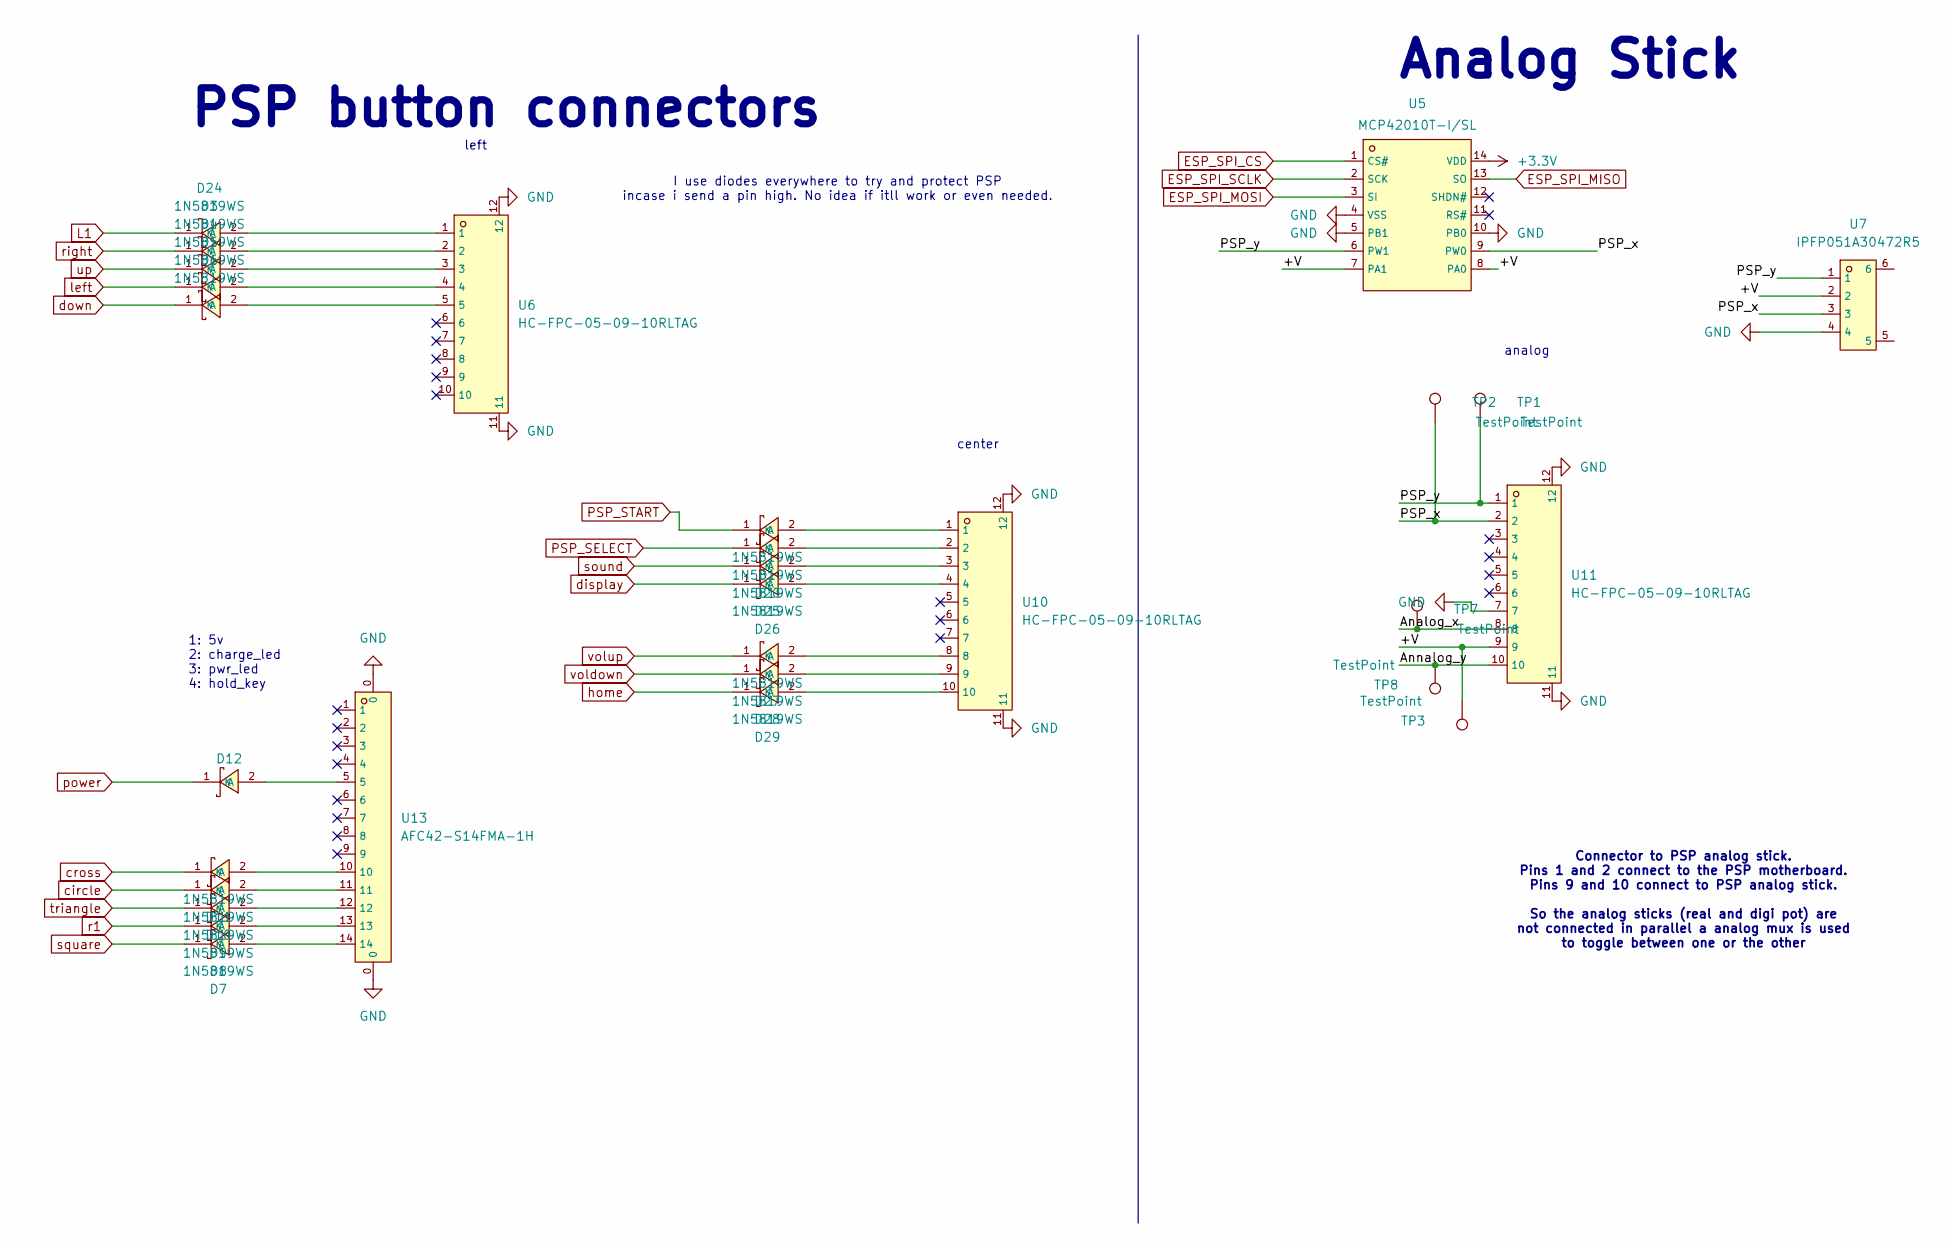
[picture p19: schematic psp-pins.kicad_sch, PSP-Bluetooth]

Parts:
D1, D3, D4, D5, D6, D7, D8, D9, D10, D11, D12, D20, D24, D25, D26, D27, D28, D29: 1N5819WS; SOD-323_L1.8-W1.3-LS2.5-RD; LCSC C191023
TP1, TP2, TP3, TP7, TP8: TestPoint; TestPoint_Pad_D1.0mm
U5: MCP42010T-I/SL; SOIC-14_L10.0-W5.5-P1.27-LS7.8-BL; LCSC C54781
U6, U10, U11: HC-FPC-05-09-10RLTAG; FPC-SMD_10P-P0.50_HC-FPC-05-09-10RLTAG; LCSC C5213750
U7: IPFP051A30472R5; FPC-SMD_4P-P0.50_C9900013912; LCSC C5127055
U13: AFC42-S14FMA-1H; CONN-SMD_14P-P0.50_L3.1-W9.0; LCSC C466533

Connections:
+3.3V: U5.14 (VDD); also elsewhere on the board
/PSP Pins 2K/+V: TP3.1, U5.7 (PA1), U5.8 (PA0), U7.2, U11.9
/PSP Pins 2K/Analog_x: TP7.1, U11.8
/PSP Pins 2K/Annalog_y: TP8.1, U11.10
/PSP Pins 2K/PSP_x: TP2.1, U5.9 (PW0), U7.3, U11.2
/PSP Pins 2K/PSP_y: TP1.1, U5.6 (PW1), U7.1, U11.1
ESP_SPI_CS: U5.1 (CS#); also elsewhere on the board
ESP_SPI_MISO: U5.13 (SO); also elsewhere on the board
ESP_SPI_MOSI: U5.3 (SI); also elsewhere on the board
ESP_SPI_SCLK: U5.2 (SCK); also elsewhere on the board
GND: U5.4 (VSS), U5.5 (PB1), U5.10 (PB0), U6.11, U6.12, U7.4, U10.11, U10.12, U11.7, U11.11, U11.12, U13.0; also elsewhere on the board
L1: D24.1 (K); also elsewhere on the board
unnamed: D1.2 (A), U10.1
unnamed: D3.2 (A), U6.2
unnamed: D4.2 (A), U6.3
unnamed: D5.2 (A), U6.4
unnamed: D6.2 (A), U6.5
unnamed: D7.2 (A), U13.14
unnamed: D8.2 (A), U13.13
unnamed: D9.2 (A), U13.12
unnamed: D10.2 (A), U13.11
unnamed: D11.2 (A), U13.10
unnamed: D12.2 (A), U13.5
unnamed: D20.2 (A), U10.2
unnamed: D24.2 (A), U6.1
unnamed: D25.2 (A), U10.3
unnamed: D26.2 (A), U10.4
unnamed: D27.2 (A), U10.8
unnamed: D28.2 (A), U10.9
unnamed: D29.2 (A), U10.10
PSP_SELECT: D20.1 (K); also elsewhere on the board
PSP_START: D1.1 (K); also elsewhere on the board
circle: D10.1 (K); also elsewhere on the board
cross: D11.1 (K); also elsewhere on the board
display: D26.1 (K); also elsewhere on the board
down: D6.1 (K); also elsewhere on the board
home: D29.1 (K); also elsewhere on the board
left: D5.1 (K); also elsewhere on the board
power: D12.1 (K); also elsewhere on the board
r1: D8.1 (K); also elsewhere on the board
right: D3.1 (K); also elsewhere on the board
sound: D25.1 (K); also elsewhere on the board
square: D7.1 (K); also elsewhere on the board
triangle: D9.1 (K); also elsewhere on the board
up: D4.1 (K); also elsewhere on the board
voldown: D28.1 (K); also elsewhere on the board
volup: D27.1 (K); also elsewhere on the board

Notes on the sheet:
I use diodes everywhere to try and protect PSP incase i send a pin high. No idea if itll work or even needed.
PSP button connectors
1: 5v 2: charge_led 3: pwr_led 4: hold_key
analog
Analog Stick
Connector to PSP analog stick. Pins 1 and 2 connect to the PSP motherboard. Pins 9 and 10 connect to PSP analog stick. So the analog sticks (real and digi pot) are not connected in parallel a analog mux is used to toggle between one or the other
left
center

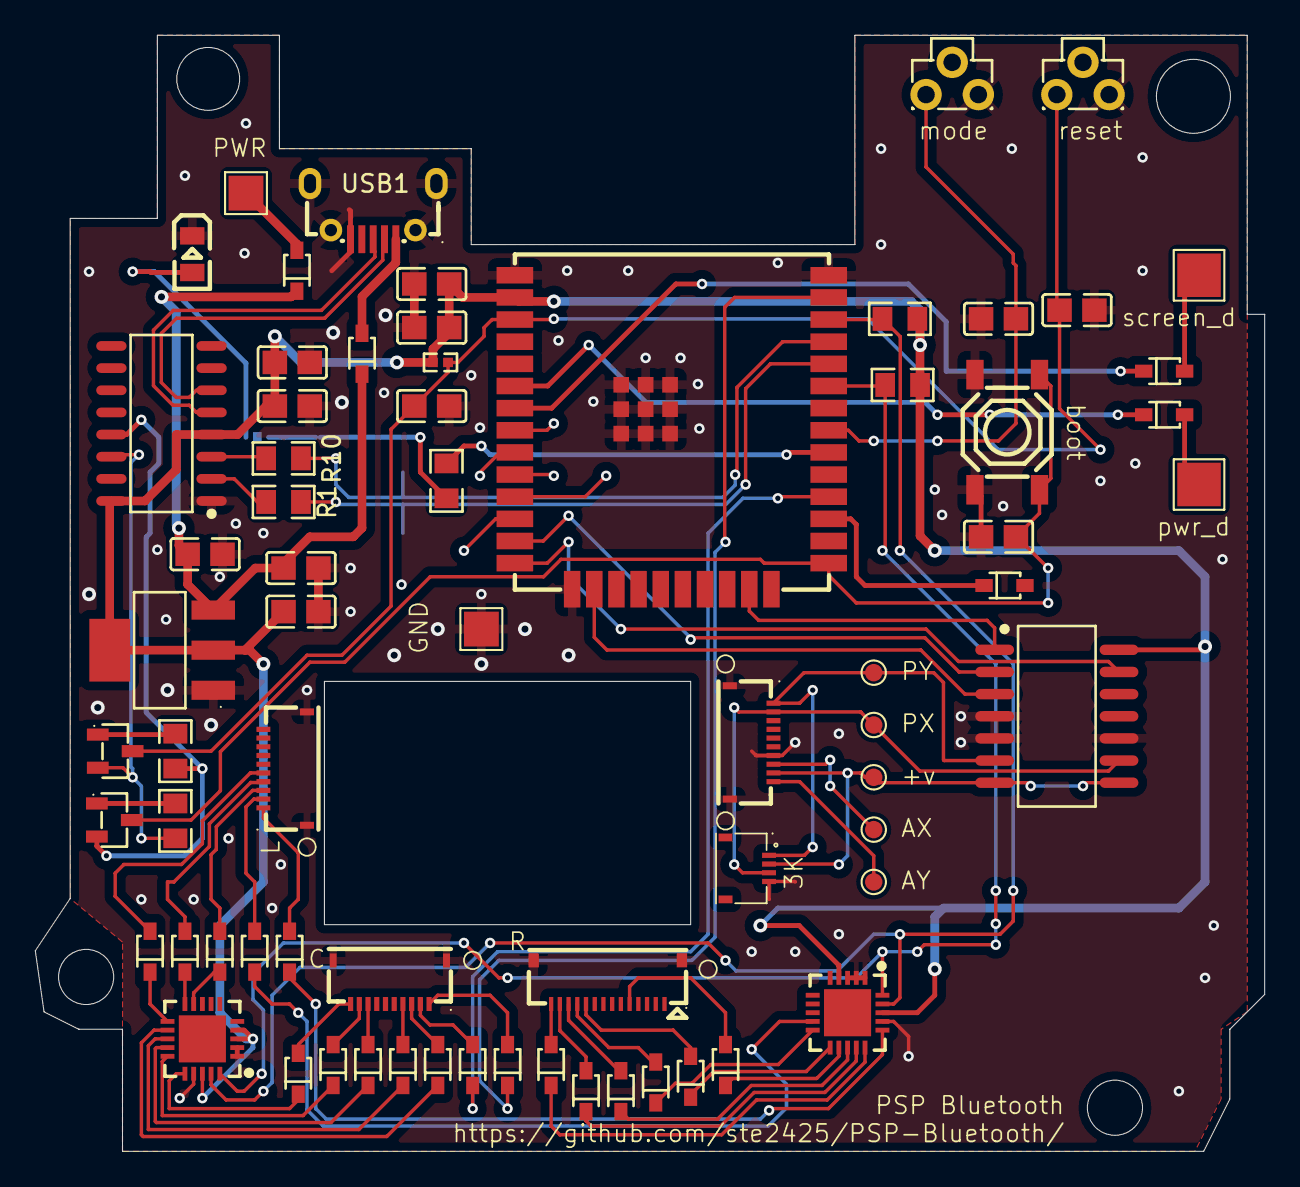
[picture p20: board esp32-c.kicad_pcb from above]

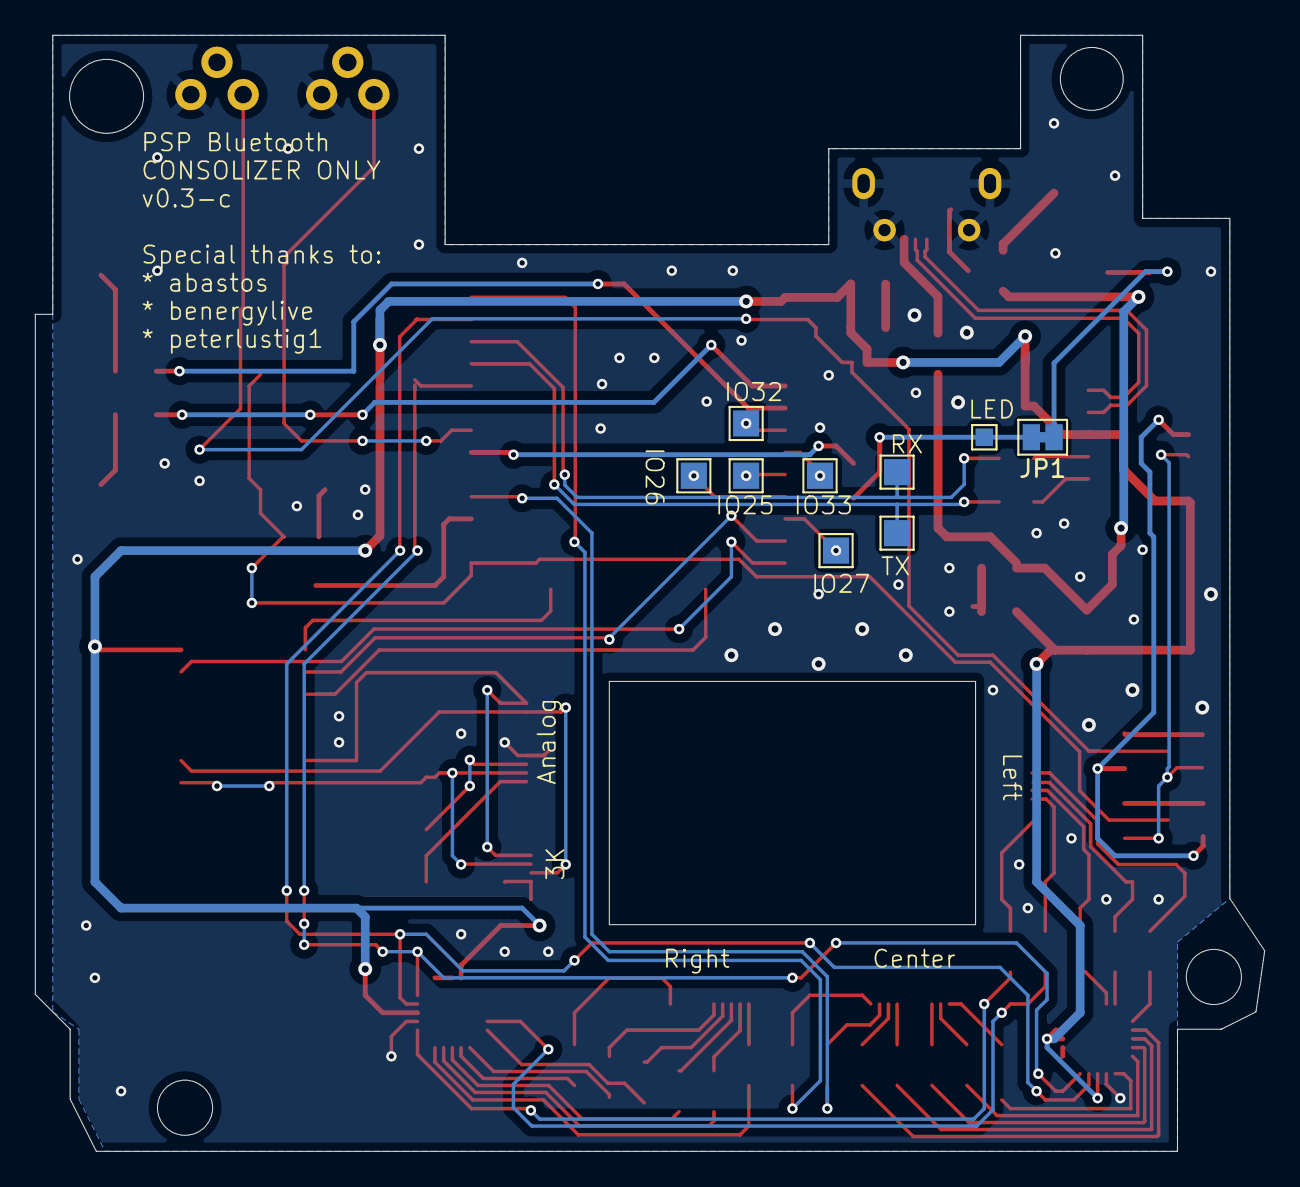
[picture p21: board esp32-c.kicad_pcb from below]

Board: 2 copper layers, 70.5 x 64.0 mm, 78 parts (9 on the bottom side), 78 nets.

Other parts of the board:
D13: 1N5819WS; SOD-323_L1.8-W1.3-LS2.5-RD

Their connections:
GPIO_GND: D13.1 (K); also elsewhere on the board

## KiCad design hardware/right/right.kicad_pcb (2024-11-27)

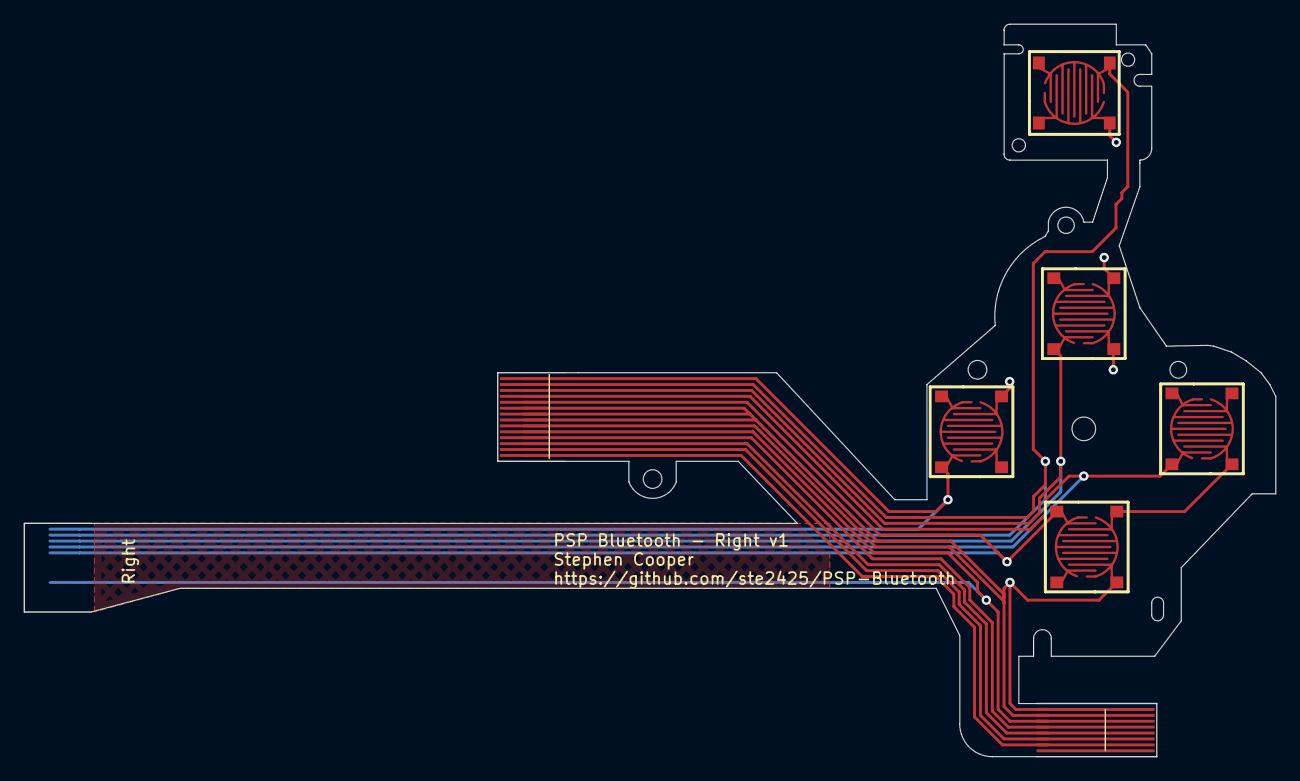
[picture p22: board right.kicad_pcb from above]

Board: 2 copper layers, 105.9 x 62.0 mm, 8 parts (1 on the bottom side), 11 nets.

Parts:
C1, C4: flex-conector_14; flex_long_14
C3: flex-conector_8_1; flex_long_8
L2, L3, L4, L5, L6: SKRRABE010; KEY-SMD_4P-L5.2-W5.2-P3.70-LS6.4_1

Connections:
/Circle: C1.4, C4.11, L6.1
/LED +5v: C3.7, C4.1
/R1: C1.2, C4.13, L3.1
/Square: C1.1, C4.14, L5.1
/Triangle: C1.3, C4.12, L4.1
/chargeLED: C3.6, C4.2
/cross: C1.5, C4.10, L2.1
/gnd: C3.1, C3.2, C4.6, C4.7, C4.8, C4.9, L2.2, L3.2, L4.2, L5.2, L6.2
/keyHold: C3.4, C4.4
/keyPower: C1.10, C3.3, C4.5
/powerLED: C3.5, C4.3

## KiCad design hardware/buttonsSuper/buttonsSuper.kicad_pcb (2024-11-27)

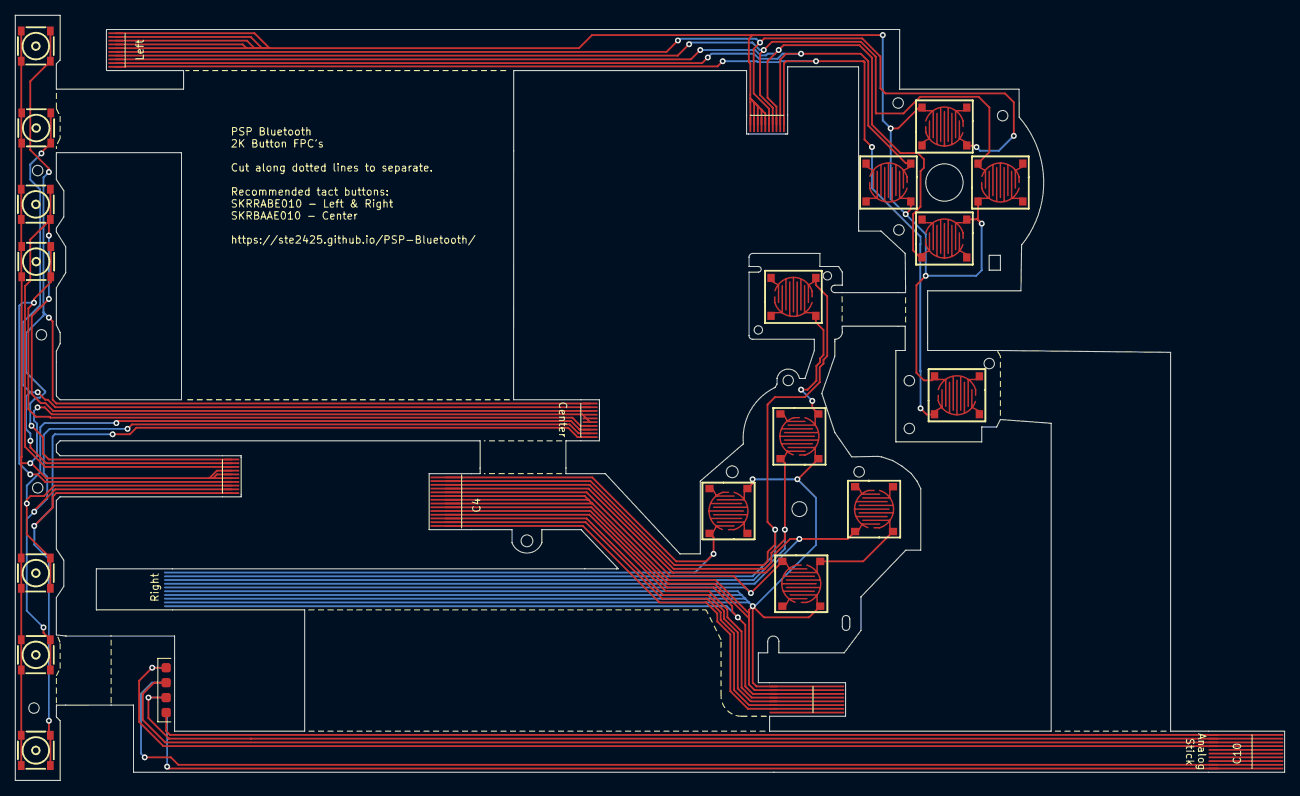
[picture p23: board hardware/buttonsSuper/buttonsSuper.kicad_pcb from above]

Board: 2 copper layers, 170.0 x 102.5 mm, 26 parts (1 on the bottom side), 31 nets.

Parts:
C1, C2, C8, C9: flex-conector_10; flex_short_10
C3: flex-conector_8_1; flex_long_8
C4: flex-conector_14; flex_long_14
C5, C10: flex-conector_10; flex_long_10
C6: PSP-analog
DOWN1: SKRRABE010; KEY-SMD_4P-L5.2-W5.2-P3.70-LS6.4_1
L1, L2, L3, L4, L5, L6: SKRRABE010; KEY-SMD_4P-L5.2-W5.2-P3.70-LS6.4_1
LEFT1: SKRRABE010; KEY-SMD_4P-L5.2-W5.2-P3.70-LS6.4_1
RIGHT1: SKRRABE010; KEY-SMD_4P-L5.2-W5.2-P3.70-LS6.4_1
U1, U2, U3, U4, U5, U6, U7: SKRBAAE010; KEY-SMD_4P-L4.8-W4.8-P3.65_SKRBAAE010
UP1: SKRRABE010; KEY-SMD_4P-L5.2-W5.2-P3.70-LS6.4_1

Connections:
/+v: C6.3 (Analog_+v), C6.7 (PSP_+v), C10.2 (+v)
/Analog_y: C6.4 (Analog_y), C10.1 (Analog_y)
/Circle: C4.11, C5.4, L6.1
/LED +5v: C3.7, C4.1
/PSP_x: C6.6 (PSP_x), C10.9 (PSP_x)
/PSP_y: C6.8 (PSP_y), C10.10 (PSP_y)
/R1: C4.13, C5.2, L3.1
/Square: C4.14, C5.1, L5.1
/Triangle: C4.12, C5.3, L4.1
/analog_x: C6.2 (Analog_x), C10.3 (Analog_X)
/chargeLED: C3.6, C4.2
/cross: C4.10, C5.5, L2.1
/down: C1.5, C2.5, DOWN1.1
/gnd: C3.1, C3.2, C4.6, C4.7, C4.8, C4.9, C5.6, C5.7, C5.8, C5.9, L2.2, L3.2, L4.2, L5.2, L6.2
/gnd2: C8.4, C8.5, C8.6, C9.4, C9.5, C9.6, U1.1, U1.3, U2.1, U2.3, U3.1, U3.3, U4.1, U4.3, U5.1, U5.3, U6.1, U6.3, U7.1, U7.3
/gnd3: C6.1 (Analog_gnd), C6.5 (PSP_gnd), C10.4 (gnd)
/home: C8.10, C9.10, U7.2, U7.4
/keyHold: C3.4, C4.4
/keyPower: C3.3, C4.5, C5.10
/l1: C1.1, C2.1, L1.1
/left: C1.4, C2.4, LEFT1.1
/music: C8.3, C9.3, U1.2, U1.4
/powerLED: C3.5, C4.3
/right: C1.2, C2.2, RIGHT1.1
/screen: C8.7, C9.7, U2.2, U2.4
/select: C8.2, C9.2, U4.2, U4.4
/start: C8.1, C9.1, U3.2, U3.4
/up: C1.3, C2.3, UP1.1
/vol down: C8.9, C9.9, U6.2, U6.4
/vol up: C8.8, C9.8, U5.2, U5.4
GND: C1.6, C1.7, C1.8, C1.9, C1.10, C2.6, C2.7, C2.8, C2.9, C2.10, DOWN1.2, L1.2, LEFT1.2, RIGHT1.2, UP1.2

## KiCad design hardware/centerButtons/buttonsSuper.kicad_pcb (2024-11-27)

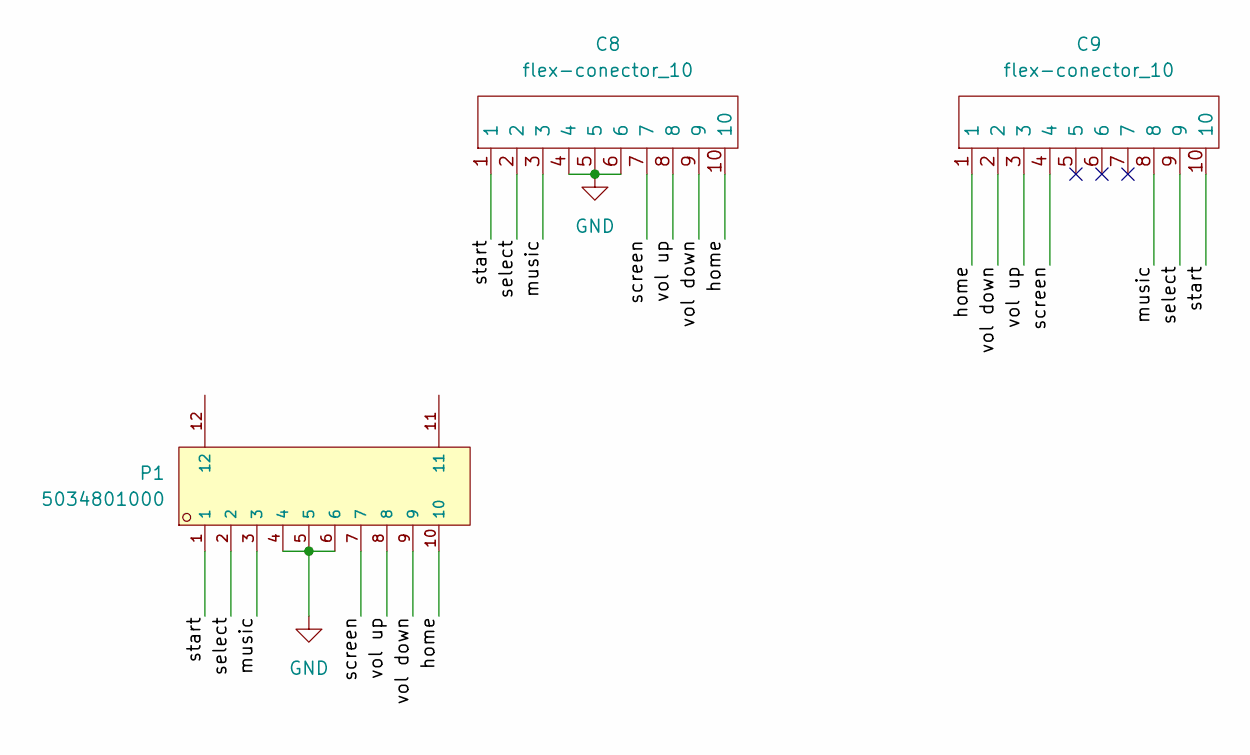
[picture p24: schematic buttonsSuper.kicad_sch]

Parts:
C8, C9: flex-conector_10; flex_short_10
P1: 5034801000; FPC-SMD_5034801000; LCSC C127355

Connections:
/home: C8.10, C9.1, P1.10
/music: C8.3, C9.8, P1.3
/screen: C8.7, C9.4, P1.7
/select: C8.2, C9.9, P1.2
/start: C8.1, C9.10, P1.1
/vol down: C8.9, C9.2, P1.9
/vol up: C8.8, C9.3, P1.8
GND: C8.4, C8.5, C8.6, P1.4, P1.5, P1.6

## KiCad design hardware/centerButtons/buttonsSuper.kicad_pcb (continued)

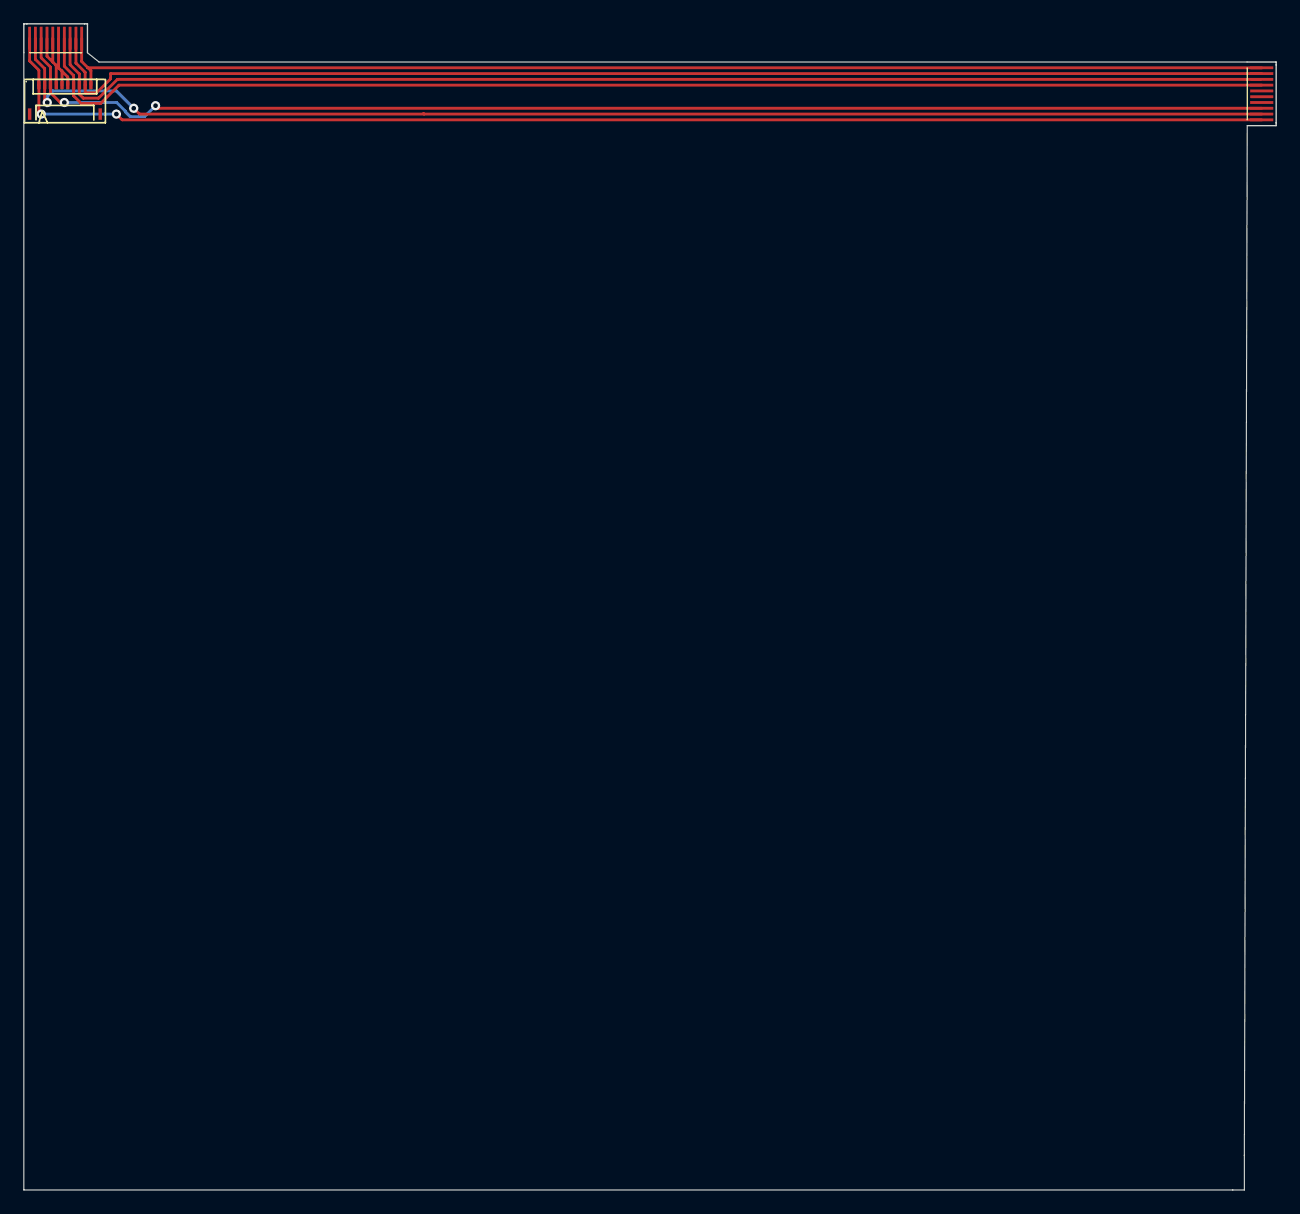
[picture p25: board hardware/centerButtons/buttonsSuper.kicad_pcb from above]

Board: 2 copper layers, 108.2 x 100.8 mm, 3 parts (0 on the bottom side), 8 nets.

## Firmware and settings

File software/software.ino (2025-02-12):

#include <Bluepad32.h>
#include "src/digipot.h"
#include "src/led.h"
#include "src/PSPState.h"
#include "src/Button.h"
#include "src/Mappings.h"
#include <LittleFS.h>
#include "src/controllerManager.h"
#include "src/interop.h"
#include "src/timeout.h"
#include "src/Settings.h"

Timeout disableNewConnectionTimer;

void disableNewConnections() {
  CTRMANAGER_enableConnections(false);
}

void setup() { 
    disableNewConnectionTimer.setCallback(disableNewConnections);
    disableNewConnectionTimer.setTimeout(1000);
    disableNewConnectionTimer.start();

    Serial.begin(115200);

    LittleFS.begin(true);

    // muse be first everything else expects settings to be loaded
    SETTINGS_setup();

    DIGIPOT_setup();
    BUTTON_setup();
    PSPState_setup();
    MAPPINGS_setup();
    CTRMANAGER_setup();
    LED_setup();
    INTEROP_setup();

    INTEROP_enableBLEService(false);
}

void loop() {    
  disableNewConnectionTimer.loop();
  LED_loop();
  
  BUTTON_loop();
  CTRMANAGER_loop();
  INTEROP_loop();

  delay(1);
}

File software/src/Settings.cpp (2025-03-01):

#include "Settings.h"
#include <ArduinoJson.h>

Settings SETTINGS_current;

void SETTINGS_setup() {
  JsonDocument doc;

  Serial.println("Loading Settings Saved");
  String savedMappings = FileUtility::readFile(LittleFS, "/settings.json");
  auto len = savedMappings.length() + 1;
  char dataArr[len];
  savedMappings.toCharArray(dataArr, len);

  deserializeJson(doc, dataArr, len);

  if (doc.isNull()) {  
    Serial.println("Settings Saved empty: Loading default");  
    doc = NULL;
    deserializeJson(doc, SETTINGS_DEFAULT, strlen(SETTINGS_DEFAULT));
  }

  SETTINGS_current.useExtraCombo = (bool)doc["useExtraCombo"];
  SETTINGS_current.ledBrightness = (uint16_t)doc["ledBrightness"];
  SETTINGS_current.throttleThreshold = (uint16_t)doc["throttleThreshold"];
  SETTINGS_current.analogThreshold = (uint16_t)doc["analogThreshold"];
  SETTINGS_current.diagonalThreshold = (uint16_t)doc["diagonalThreshold"];
  SETTINGS_current.screenDelay = (uint16_t)doc["screenDelay"];
  SETTINGS_current.coldBootDelay = (uint16_t)doc["coldBootDelay"];
  SETTINGS_current.warmBootDelay = (uint16_t)doc["warmBootDelay"];
  SETTINGS_current.shutdownDelay = (uint16_t)doc["shutdownDelay"];
  SETTINGS_current.useAlternativeShutdown = (bool)doc["useAlternativeShutdown"];
  SETTINGS_current.batteryWarning = (uint16_t)doc["batteryWarning"];
  SETTINGS_current.dblClickMode = (uint16_t)doc["dblClickMode"];
  SETTINGS_current.lngClickMode = (uint16_t)doc["lngClickMode"];
  SETTINGS_current.clickMode = (uint16_t)doc["clickMode"];

  SETTINGS_current.screenDelay == 0 ? 600 : SETTINGS_current.screenDelay;
  SETTINGS_current.coldBootDelay == 0 ? 12000 : SETTINGS_current.coldBootDelay;
  SETTINGS_current.warmBootDelay == 0 ? 1500 : SETTINGS_current.warmBootDelay;
  SETTINGS_current.shutdownDelay == 0 ? 3000 : SETTINGS_current.shutdownDelay;
  SETTINGS_current.batteryWarning == 0 ? 51 : SETTINGS_current.batteryWarning; //20% of 255

  SETTINGS_current.lngClickMode == 0 ? 2 : SETTINGS_current.lngClickMode; // default to ble
  SETTINGS_current.clickMode == 0 ? 1 : SETTINGS_current.clickMode; // default to controller pair

  // ensure at least one click mode will enable BLE mode as a emegency backup
  if (SETTINGS_current.lngClickMode != 2 && SETTINGS_current.dblClickMode != 2 && SETTINGS_current.clickMode != 2) {
    Serial.print("WARNING: No button mode set to BLE, default long click");
    SETTINGS_current.lngClickMode = 2;
  }

  Serial.print("batteryWarning ");
  Serial.println(SETTINGS_current.batteryWarning);

  Serial.print("use screenDelay ");
  Serial.println(SETTINGS_current.screenDelay);

  Serial.print("use coldBootDelay ");
  Serial.println(SETTINGS_current.coldBootDelay);

  Serial.print("use warmBootDelay ");
  Serial.println(SETTINGS_current.warmBootDelay);

  Serial.print("use extra ");
  Serial.println(SETTINGS_current.useExtraCombo);

  Serial.print("analogThreshold");
  Serial.println(SETTINGS_current.analogThreshold);
  
  Serial.print("diagonalThreshold");
  Serial.println(SETTINGS_current.diagonalThreshold);
  
  Serial.print("throttleThreshold");
  Serial.println(SETTINGS_current.throttleThreshold);
  
  Serial.print("ledBrightness");
  Serial.println(SETTINGS_current.ledBrightness);
  
  Serial.print("shutdownDelay");
  Serial.println(SETTINGS_current.shutdownDelay);
  
  Serial.print("useAlternativeShutdown");
  Serial.println(SETTINGS_current.useAlternativeShutdown);
}

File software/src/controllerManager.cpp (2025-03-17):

#include "controllerManager.h"

Timeout pspBootTimeout;
Timeout pspScreenTimeout;
Timeout controllerTurnOffTimeout;
Timeout lowBaterryCheckTimeout;

bool pspBooting = false;
bool pspColdBoot = true;

bool batteryLow = false;

#define maxGamepads 4

ControllerPtr myControllers[maxGamepads];

void onPspBootTimeout() {
  PSPState_pressScreen();
  pspScreenTimeout.start();
}

void onPSPScreenTimeout() {
  Serial.println("Screen has been pressed");
  PSPState_releaseScreen();
  pspBooting = false;
  LED_autoSet();
}

void onLowBatteryCheck() {
 // Serial.println("Battery Timeout triggered");

  if (myControllers[0] != nullptr) {
        
    uint8_t batteryLevel = myControllers[0]->battery();
    //Serial.print("Battery level: ");
    //Serial.println(batteryLevel);

    auto batteryBelow = batteryLevel < SETTINGS_current.batteryWarning;

    if (batteryBelow && !batteryLow) {
      //Serial.println("Below threshold setting light");
      batteryLow = true;
      LED_autoSet();
    } else if(!batteryBelow && batteryLow) {      
      //Serial.println("Battery OK");
      batteryLow = false;
      LED_autoSet();
    }
    
    lowBaterryCheckTimeout.start();
  } else {    
    batteryLow = false;
  }
}

bool CTRMANAGER_isBooted() {
  return PSPstate_poweredOn();
}

void CTRMANAGER_bootConsole(bool bootOrEnd) {
  if (bootOrEnd) {
    CTRMANAGER_enableConnections(false);
    PSPState_togglePower();
    auto delayBootTime = pspColdBoot ? SETTINGS_current.coldBootDelay : SETTINGS_current.warmBootDelay;

    Serial.println("Boot delay");
    Serial.println(delayBootTime);

    pspBootTimeout.setTimeout(delayBootTime);
    pspColdBoot = false;
    pspBootTimeout.start();

    pspBooting = true;

    lowBaterryCheckTimeout.start();
  } else {
    pspBootTimeout.stop();
    pspScreenTimeout.stop();
    lowBaterryCheckTimeout.stop();

    pspBooting = false;

    if (PSPstate_poweredOn())
      PSPState_togglePower();

    INTEROP_enableBLEService(false);
  }
}

bool CTRMANAGER_batteryLow() {
  return batteryLow;
}

void CTRMANAGER_updateSettings() {
  pspScreenTimeout.stop();
  pspScreenTimeout.setTimeout(SETTINGS_current.screenDelay);
  controllerTurnOffTimeout.setTimeout(SETTINGS_current.shutdownDelay);
}

void CTRMANAGER_disconnectAll() {    
    Serial.println("Disconnecting all controllers");

    for (int i = 0; i < maxGamepads; i++) {
        if (myControllers[i] != nullptr) {
          Serial.print("Disconnecting: ");
          Serial.println(i);
          myControllers[i]->disconnect();
        }
    }

  lowBaterryCheckTimeout.stop();
  batteryLow = false;
}

void onConnectedController(ControllerPtr ctl) {
    
    bool foundEmptySlot = false;
    
    for (int i = 0; i < maxGamepads; i++) {
        if (myControllers[i] == nullptr) {       
            myControllers[i] = ctl;
            foundEmptySlot = true;

            MappingMeta *meta = MAPPINGS_current;
            ctl->setColorLED(meta->colour[0], meta->colour[1], meta->colour[2]);
            ctl->setPlayerLEDs(meta->mappingNumer & 0x0f);
            
            // if first controller
            if (i == 0 && !PSPstate_poweredOn()) {
              CTRMANAGER_bootConsole(true);
              LED_autoSet();
            }
            
            break;
        }
    }
    
    if (!foundEmptySlot) {
        Serial.println("CALLBACK: Controller connected, but could not found empty slot");
        ctl->disconnect();
    }
}

void onDisconnectedController(ControllerPtr ctl) {
  
    bool foundController = false;

    for (int i = 0; i < maxGamepads; i++) {
        if (myControllers[i] == ctl) {
            Serial.printf("CALLBACK: Controller disconnected from index=%d\n", i);
            myControllers[i] = nullptr;
            foundController = true;
            break;
        }
    }

    bool allDisconnected = true;

    for (int i = 0; i < maxGamepads; i++) {
        if (myControllers[i] != nullptr) {
            allDisconnected = false;
            break;
        }
    }
    
    if (allDisconnected) {  
      CTRMANAGER_bootConsole(false);
      LED_autoSet();
    }

    if (!foundController) {
        Serial.println("CALLBACK: Controller disconnected, but not found in myControllers");
    }

    batteryLow = false;
}

void handleButtonMapping(ControllerMapping *mapping) {
  // value over 100 means button to analog stick
  if (mapping->PSPButton > 100) {
    if (mapping->PSPButton == 101) { // right
      PSPState_analogX(510);
    } else if(mapping->PSPButton == 102) { // left
      PSPState_analogX(-510);
    } else if (mapping->PSPButton == 103) { // up
      PSPState_analogY(-510);
    } else if(mapping->PSPButton == 104) { // down
      PSPState_analogY(510);
    }
  } else {
    PSPState_markButtonAsPressed(mapping->PSPButton);
  }
}

bool CTRMANAGER_pspBooting() {
  return pspBooting;
}

void CTRMANAGER_applyColours() { 
  Serial.println("Applying colours");
    MappingMeta *hi = MAPPINGS_current;
        for (uint8_t i = 0; i < 4; i++) {
          Serial.print("Updating controller for index: ");
          Serial.println(i);

          if (myControllers[i] && myControllers[i]->isConnected()) {
              if (myControllers[i]->isGamepad()) {
                Serial.print("Applying color RGB (");
                Serial.print(hi->colour[0]);
                Serial.print(", ");
                Serial.print(hi->colour[1]);
                Serial.print(", ");
                Serial.print(hi->colour[2]);
                Serial.println(")");

                myControllers[i]->setColorLED(hi->colour[0], hi->colour[1], hi->colour[2]);

                auto indicatorNumber = hi->mappingNumer & 0x0f;
                Serial.print("Setting player indicator: ");
                Serial.println(indicatorNumber);
                myControllers[i]->setPlayerLEDs(indicatorNumber);
                
              } else {
                  Serial.println("Unsupported controller");
              }
          }
        }
}

bool changingMapping = false;

void proccessControllerButton(ControllerPtr ctl, ControllerMapping *mapping) {
  auto isL2 = mapping->ControllerBit == 6;
  auto isR2 = mapping->ControllerBit == 7;
  auto brakeVal = ctl->brake();
  auto throttleVal = ctl->throttle();
  auto pressed = false;

  if (!isL2 && !isR2) {
    if (bitRead(ctl->buttons(), mapping->ControllerBit))
      handleButtonMapping(mapping);
  } else {
    if (brakeVal == 0 && throttleVal == 0)
      pressed = bitRead(ctl->buttons(), mapping->ControllerBit);
    else if ((isL2 && ctl->brake() > SETTINGS_current.throttleThreshold) || (isR2 && ctl->throttle() > SETTINGS_current.throttleThreshold))
      pressed = true;

    if (pressed)
      handleButtonMapping(mapping);
  }
}

bool pressingHome = false;
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

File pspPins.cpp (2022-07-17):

#include "pspPins.h"

const uint8_t PSP_HOME = 0;
const uint8_t PSP_START = 1;
const uint8_t PSP_SELECT = 2;
const uint8_t PSP_DISPLAY = 3;
const uint8_t PSP_L1 = 4;
const uint8_t PSP_DUP = 5;
const uint8_t PSP_DDOWN = 6;
const uint8_t PSP_DRIGHT = 7;
const uint8_t PSP_DLEFT = 8;
const uint8_t PSP_R1 = 9;
const uint8_t PSP_CROSS = 10;
const uint8_t PSP_CIRCLE = 11;
const uint8_t PSP_SQUARE = 12;
const uint8_t PSP_TRIANGLE = 13;
const uint8_t PSP_POWER = 14;
const uint8_t PSP_LS_LEFT = 15;
const uint8_t PSP_LS_RIGHT = 16;
const uint8_t PSP_LS_UP = 17;
const uint8_t PSP_LS_DOWN = 18;
const uint8_t PSP_LS = 19;

const uint8_t pinCount = 14;
bool pspPoweredOn = false;

bool XAxisToBeReset = false;
bool YAxisToBeReset = false;


uint8_t pins[pinCount] = {
  17, // home
  14, // start
  15, // select
  16, // display
  6, //l1
  7, // dup
  9, //ddown
  18, // dright
  8, //dleft
  5, //r1
  2, //cross
  3, // circle
  19, // square
  4, // triangle
 // 21 // power
};

bool pinPressed[pinCount] = {
  false,
  false,
  false,
  false,
  false,
  false,
  false,
  false,
  false,
  false,
  false,
  false,
  false,
  false,
 // false,
};

void PSP_mark_all_for_release() {
  for(int i = 0; i < pinCount; i++) {
    if (i != PSP_POWER)
      pinPressed[i] = false;
  }

  XAxisToBeReset = true;
  YAxisToBeReset = true;
}

void PSP_release_unused() {
  for(int i = 0; i < pinCount; i++) {
    if (pinPressed[i] == false) {            
      pinMode(pins[i], INPUT);
    }
  }

  if (XAxisToBeReset) {
    DIGIPOT_write_x(127);
  }
  
  if (YAxisToBeReset) {
    DIGIPOT_write_y(127);
  }
}

bool isButtonLS(uint8_t pspButton) {
  return pspButton == PSP_LS_LEFT ||
    pspButton == PSP_LS_RIGHT ||
    pspButton == PSP_LS_UP ||
    pspButton == PSP_LS_DOWN;
}

void PSP_set_ls(uint8_t x, uint8_t y) {
      uint8_t xToSet = constrain(x, 50, 200);
      XAxisToBeReset = false;
      DIGIPOT_write_x(xToSet);
      
      uint8_t yToSet = constrain(y, 50, 200);
      YAxisToBeReset = false;
      DIGIPOT_write_y(yToSet);
}

void moveLS(uint8_t pspButton) {  
  switch(pspButton) {
    case PSP_LS_LEFT:
      Serial.println("Moving LS LEFT");
      XAxisToBeReset = false;
      DIGIPOT_write_x(50);
    break;
    case PSP_LS_RIGHT:
      Serial.println("Moving LS RIGHT");
      XAxisToBeReset = false;
      DIGIPOT_write_x(200);
    break;
    case PSP_LS_UP:
      Serial.println("Moving LS LEFT");
      YAxisToBeReset = false;
      DIGIPOT_write_y(50);
    break;
    case PSP_LS_DOWN:
      Serial.println("Moving LS RIGHT");
      YAxisToBeReset = false;
      DIGIPOT_write_y(200);
    break;
  }
}

void PSP_press_button (uint8_t pspButton) {
  if (isButtonLS(pspButton)) {
    moveLS(pspButton);
  } else {
    pinPressed[pspButton] = true;
      
    pinMode(pins[pspButton], OUTPUT);
    digitalWrite(pins[pspButton], LOW);
  }
}

void toggle_power() {
  Serial.println("Toggle Power");
  
  pinMode(21, OUTPUT);
  digitalWrite(21, LOW);
  delay(500);
  pinMode(21, INPUT);
}

bool coldBoot = true;

bool PSP_power_on() {
  bool isColdBoot = coldBoot;

  coldBoot = false;
  
  if (!pspPoweredOn) {
    Serial.println("Powering on");
    pspPoweredOn = true;

    toggle_power();
  }

  return isColdBoot;
}

void PSP_power_off() {
  if (pspPoweredOn) {
    Serial.println("Powering off");
    pspPoweredOn = false;

    toggle_power();
  }
}

void PSP_press_screen() {
  Serial.println("Press screen");
  pinMode(pins[PSP_DISPLAY], OUTPUT);
  digitalWrite(pins[PSP_DISPLAY], LOW);
}

void PSP_release_screen() {
  Serial.println("Release screen");
  pinMode(pins[PSP_DISPLAY], INPUT);
}

void PSP_toggle_screen(){
  Serial.println("Toggle screen");
  
  pinMode(pins[PSP_DISPLAY], OUTPUT);
  digitalWrite(pins[PSP_DISPLAY], LOW);
  delay(5000);
  pinMode(pins[PSP_DISPLAY], INPUT);
  Serial.println("Toggle screen - DONE");
}

uint8_t PSP_map_controller(int controllerVal) {  
  /*
   * Controllers report range of -511 - 512
   * bring to 0 - 1023 then map to Digital pots acceptable range.
   * Digi pot accepts 0 - 257 however
   * for some reason PSP reports full range from a value of 50 - 200.
   */
   
  return map(controllerVal + 511, 0, 1023, 200, 50);
}

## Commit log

2022-04-09 Fix instant release of button problem
2022-05-12 Adding system buttons
2022-06-07 Analog stick (#1)
    Added hardware V1
    [psp-bluetooth-B_Cu.gbr, psp-bluetooth-B_Mask.gbr, psp-bluetooth-B_Silkscreen.gbr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]
2022-07-17 Added Mappings (#2)
    * Initial work and hardware stuff
    * Move around stuff
    * Adding mappings for analogue sticks
    * Added PCB pinout
    * Final
    [psp-bluetooth-B_Cu.gbr, psp-bluetooth-B_Mask.gbr, psp-bluetooth-B_Silkscreen.gbr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]
2022-08-01 Hardware v3 (#3)
    * Added hardware v3
    [psp-bluetooth-B_Cu.gbr, psp-bluetooth-B_Mask.gbr, psp-bluetooth-B_Silkscreen.gbr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]
2022-09-26 Made kicad project portable and finished V1.
    [psp-bluetooth-B_Cu.gbr, psp-bluetooth-B_Mask.gbr, psp-bluetooth-B_Silkscreen.gbr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]
2022-09-29 Added 3D printable mount, updated docs
    [PSP and Arduino mount (2017).skp, PSP and Arduino mount (2018).skp, PSP and Arduino mount (2019).skp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]
2022-09-29 Added boot LED & controller LED support
2022-10-23 Added controller LED stuff
2024-05-31 Clean house
    [PSP and Arduino mount (2017).skp, PSP and Arduino mount (2018).skp, PSP and Arduino mount (2019).skp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]
2024-11-27 Develop (#13)
    * Initial WIP. PSP buttons works. BLE not tested
    * wip
    * wup
    * wip
    * Added actions for PSP Bluetoothj
    * Name Github action properly
    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
    [BOM-buttonsSuper.csv, BOM-esp32-c.csv, BOM-esp32.csv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]
2024-11-30 Potentially fully working
    * Added button controls
    * Added status LED
    * Made PSP booting async to not block status LED pattern
2024-12-01 Improved landing page for web app
2024-12-06 [1.1.0] Added abiloity to reload saved button mappings
2024-12-06 Fixe dpotential issue with corrupted JSON - maybe
    [bt_service.cpp]
2025-01-08 [Hardware] Added LED pad and changed switch to right angle
    [BOM-esp32-c.csv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]
2025-01-17 [Software] Fix issue for OTA update which PSP powered on.
    [bt_service.cpp, controllerManager.cpp, interop.cpp]
2025-02-02 [Software] Changes button combo for cycle mappings. Added display button combo
2025-02-04 [Software] changed analog to button sensitivity to handle diaganols,
2025-02-12 [software] fix led
2025-02-18 [Installer] Settings page -added shutdown timer, low battery
2025-03-01 [Software] Added ability to configure mode button
2025-03-05 [Installer] Added button mode settings
2025-03-05 [Software] hange toggle power to just shutdown
2025-03-17 [Software] Fix mappings configuration via web app
    [Mappings.cpp, bt_service.cpp, controllerManager.cpp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]
